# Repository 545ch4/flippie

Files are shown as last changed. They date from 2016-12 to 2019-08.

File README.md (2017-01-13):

# flippie

first flippie test

## Basic idea and some background

Usual story: no money, lots of deadlines, unsustainable promises, social responsibility, no time at all, but the unique opportunity to get an additional time-sink. Yeah. Seconds later, I got two huge flip-dot displays I couldn't even carry myself and a lot of single modules. Soon (measured in seasons) it became obvious, that reverse engineering the RS485 based IBIS bus would not make me very happy in the long run. So I decided to throw away the original controller board and drive the flip-dot modules myself. **The goal would be a non intrusive board to directly connect any BROSE display (or array of the same) through the proprietary 60-pin connector...**  So, this is the story of that effort...

### Flip-dot display in general

A flip-dot display consists of a grid of small magnet embedded discs that are black on one side and a bright color on the other (typically white or yellow). The discs are attached to an axle with separate solenoids arranged at the ends or side. By pulsing the solenoid coil with the appropriate electrical polarity, the permanent magnet on the discs align itself with the magnetic field and thus turning (flipping) the disc.

The matrix schematic arranged on a two-dimensional area is shown below.

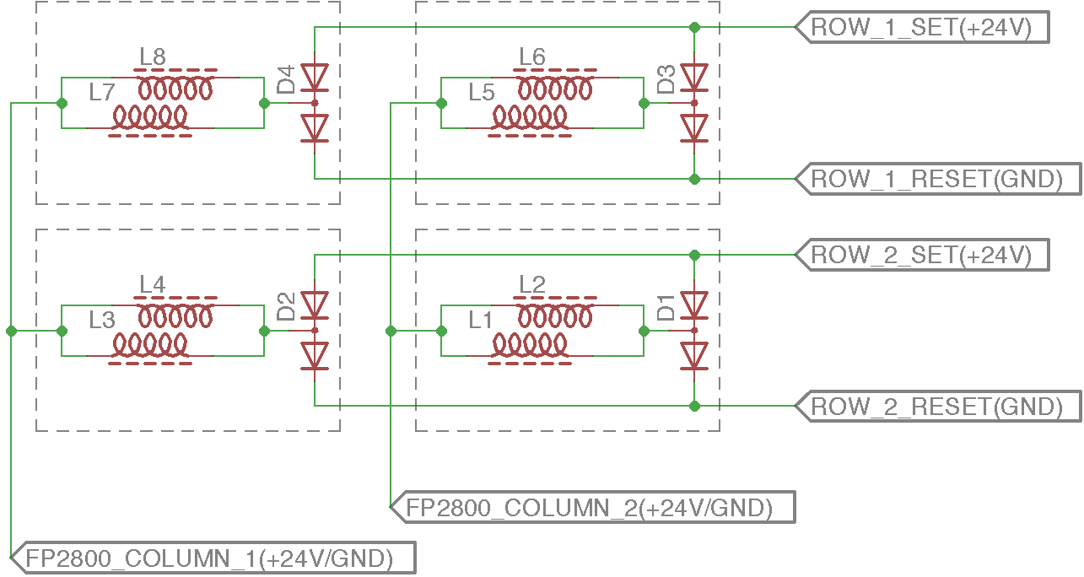
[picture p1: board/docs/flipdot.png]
flip-dot solenoid schematic


### BROSE flip-dot

Most BROSE flip-dots are equipped with an [origial FP2800A (or clone)](https://reaktor23.org/_media/projects/flipdot/fp2800-datasheet.pdf) decoder driver as column-selector. It drives one line addressed by 5-bits (A0, A1, A2, B1 and B2) in the direction of D (GND or +VS).  Based on the truth-table, 28 independent column-lines can be driven.

The address lines (ADDR1..ADDR8) are compared to an DIP-switch on each module using a 74HCT688. The output of that comparison drives the ENABLE pin of the FP2800A (through a discrete inverter).

All data and address lines are at 24V logic level. The VS line should be current limited to 350-400 mA, because the coils and/or the FP2800A may blow at higher current.

I did a reverse engineering of the 24V logic at the BROSE display just for illustration. Download as [PDF](https://github.com/545ch4/flippie/raw/master/board/docs/brose_24v_logic.pdf) or [Eagle SCH](https://github.com/545ch4/flippie/raw/master/board/docs/brose_24v_logic.sch).

### BROSE 60-pin connector

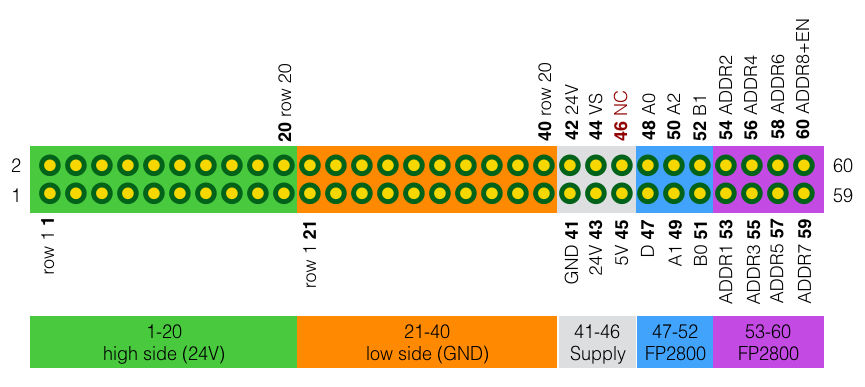
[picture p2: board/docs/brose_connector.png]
Specification of the common 60-pin BROSE connector


## flippie board

The board was designed to drive every serial assembly of modules or single ones non-intrusively - without soldering or modifying the module(s) - simply by connection the proprietary 60-pin BROSE connector. The main MCU [ESP8266](https://espressif.com/en/products/hardware/esp8266ex/overview) is mounted on a USB-interfaced USB-to-Serial converter for convenient programming and WiFi on board. Please see [wemos D1 mini](https://www.wemos.cc/product/d1-mini.html) documentation. Usually you need some driver for the converter to be detected as serial port depending on your OS. The wemos D1 mini comes with a Jiangsu Qinheng CH340/CH341/CH34X or Silicon Labs CP210x chip.

### Block diagram

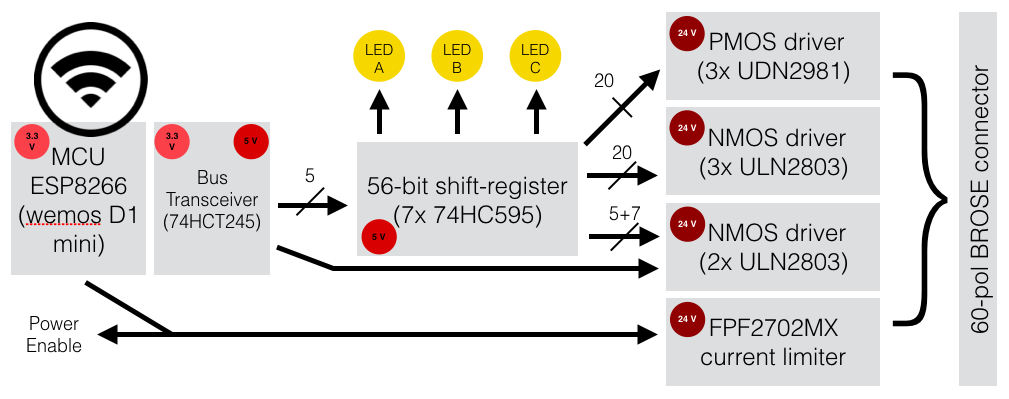
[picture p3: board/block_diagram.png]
flippie block diagram


### Schematics

Since this is my first PCB, the schematic may be slightly unusual. But it works... Suggestions are very welcome. Get the [Eagle SCH file](https://github.com/545ch4/flippie/raw/master/board/flippie.sch) or see the [PDF file](https://github.com/545ch4/flippie/raw/master/board/flippie_schematics.pdf).

### Layout

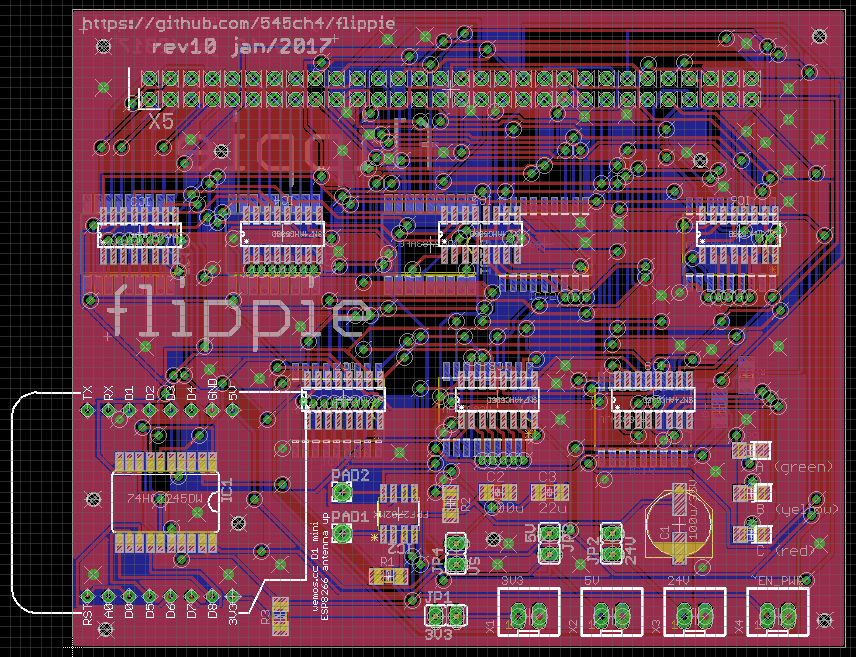
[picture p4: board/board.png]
flippie board


Download the [Eagle BRD](https://github.com/545ch4/flippie/board/flippie.brd) file and/or the generated [GERBER files as ZIP archive](https://github.com/545ch4/flippie/raw/master/board/gerber.zip). All design rules are taken from [SparkFuns Extended Gerber Format](https://github.com/sparkfun/SparkFun_Eagle_Settings/blob/master/cam/sfe-gerb274x-withGBP.cam).

### BOM

| Part | Value | Device | Package | Description |
|---|---|---|---|---|
| Part Value | Device | Package | Description |
| C1 | 100uF/50V | CPOL-EU_E | PANASONIC_E | Polarized capacitor, 50V |
| C2 | 10uF/50V | C-EU_C1206 | C1206 | X7R Ceramic Capacitor, 50V |
| C3 | 1uF/50V | C-EU_C1206 | C1206 | X7R Ceramic Capacitor, 50V |
| IC1 | 74HCT245DW | 74HCT245DW | SO20W | Octal BUS TRANSCEIVER, 3-state, TTL/CMOS |
| IC2 | FPF2702MX | FPF2700 | SO8N | AccuPower 0.4~2 A Adjustable Over-Current Protection Load Switch |
| IC3 | SN74AHC595D | SN74AHC595D | SO16N | 8 bit Shift registers |
| ... | ... | ... | ... | ... |
| IC9 | SN74AHC595D | SN74AHC595D | SO16N | 8 bit Shift registers |
| IC10 | TD62783AFG | UDN2981LW | SO18W | PMOS Darlington transistor array |
| IC11 | TD62783AFG | UDN2981LW | SO18W | PMOS Darlington transistor array |
| IC12 | TD62783AFG | UDN2981LW | SO18W | PMOS Darlington transistor array |
| IC13 | ULN2803A | ULN2803ADW | SO18W | NMOS Darlington transistor array |
| ... | ... | ... | ... | ... |
| IC17 | ULN2803A | ULN2803ADW | SO18W | NMOS Darlington transistor array |
| JP1 | 3V3 | JP1E | JP1 | 3.3V Rail Jumper |
| JP2 | 24V | JP1E | JP1 | 24V Rail Jumper |
| JP3 | 5V | JP1E | JP1 | 5V(VCC) Rail Jumper |
| JP4 | VS | JP1E | JP1 | 24V(VS) Jumper |
| LED1 C (red) | LED_SMT1206 | 1206 | LED |
| LED2 B (yellow) | LED_SMT1206 | 1206 | LED |
| LED3 A (green) | LED_SMT1206 | 1206 | LED |
| MCU1 | WEMOS D1 mini | WEMOS D1 mini | WEMOS D1 mini MCU |
| PAD1 (24V) | 2,15/1,0 | 2,15/1,0 | THROUGH-HOLE PAD |
| PAD2 (VS) | 2,15/1,0 | 2,15/1,0 | THROUGH-HOLE PAD |
| R1 | 680K | R-EU_R1206 | R1206 | Current limiter Resistor R_set |
| R2 | 100K | R-EU_R1206 | R1206 | Resistor |
| R3 | 10K | R-EU_R1206 | R1206 | Resistor |
| R4 | 10K | R-EU_R1206 | R1206 | Resistor |
| R5 | 10K | R-EU_R1206 | R1206 | Resistor |
| R6 | 220 | R-EU_R1206 | R1206 | Resistor |
| R7 | 220 | R-EU_R1206 | R1206 | Resistor |
| R8 | 220 | R-EU_R1206 | R1206 | Resistor |
| X1 | 3V3 | JST-XH-02 | JST-XH-02-PACKAGE-LONG-PAD | JST XH Connector 2 Pin |
| X2 | 5V | JST-XH-02 | JST-XH-02-PACKAGE-LONG-PAD | JST XH Connector 2 Pin |
| X3 | 24V | JST-XH-02 | JST-XH-02-PACKAGE-LONG-PAD | JST XH Connector 2 Pin |
| X4 | ~EN_PWR | JST-XH-02 | JST-XH-02-PACKAGE-LONG-PAD | JST XH Connector 2 Pin |
| X5 | BROSE-60-POL | 057-060-1 | 057-060-1 | 60-pol. BROSE CONNECTOR |

### Soldering notes

You can override the whole current limit circuit by shorting/bridging PAD1 (24V) and PAD2 (VS). If you decided to do so, you don't need to populate C1, C2, C3, R1, R2 and IC2.

> **Close JP1 (3V3) and JP2 (24V) but not JP4 (VS) yet.**

## Code

### Prerequisites

Since building and maintaining an ESP8266 toolchain using the [Arduino ESP8266 Framework](https://github.com/ESP8266/Arduino) can be rather frustrating, I decided to use [PlatformIO](http://platformio.org/platformio-ide) with this project.

1. [Download PlatformIO](http://platformio.org/platformio-ide) and install
2. Launch and follow on-screen instructions (install Python-2.7 if necessary)
3. [Install Clang/LLVM](http://docs.platformio.org/en/stable/ide/atom.html#ide-atom-installation-clang)
4. Ensure `platformio-ide` and `platformio-ide-terminal` are enabled (*"Settings > Packages"*)

### Open the project

Download or clone this repository. Open the directory `./code/server` using *"Open project"* at PlatformIO IDE.

### Necessary adoptions

Review you flip-dot addresses: **ADDR8 (8 on the DIP-switch) must be in ON state. We are emulating an overall-enable-pin with that one. Further, the addresses are inverted. So, address 0x01 matches the DIP-switch configuration 1-OFF, 2-ON, ..., 7-ON an 8-ON.**

Before you compile and upload your custom firmware to the ESP8266, there are some values specific to your setup/environment to be defined.
**Flip-dot configuration at `code/server/flippie_device.cpp`:**
```c++
// TODO: How many modules does your display consists of?
const unsigned int num_modules = 4;
config.num_modules = num_modules;
// TODO: What are the addresses (as decimal) of the modules? (see DIP-switches at each module)
config.addresses = new unsigned int[num_modules]{1, 2, 4, 8};
// TODO: How many rows does your display have? (equal over all modules)
config.num_rows = 18;
// TODO: How many columns does each module of your display have? (same order as the addresses)
config.num_columns = new unsigned int[num_modules]{28, 28, 28, 21};
// TODO: Should LED C toggle on each shift-register firing?
config.led_mode = LED_MODE_FLASHING;
```

**WiFi configuration at `code/server/main.cpp`:**
```c++
// TODO: What's the SSID of your WiFi?
const char* ssid = "SSID";
// TODO: What's the PASSWORD of your WiFi?
const char* password = "PASSWORD";
// TODO: If you don't want to use DHCP, provide a static IP (uncomment the following lines). Otherwise leave this commented.
// IPAddress ip(192, 168, 1, 23);
// IPAddress gateway(192, 168, 1, 1);
// IPAddress subnet(255, 255, 255, 0);
// WiFi.config(ip, gateway, subnet);
```

### Compile and upload firmware

> **Please disconnect the power supply of your flippie board or remove the jumper JP1 und JP3 before connecting your computer to the USB port of the ESP8266 (if mounted at the flippie board already).**

Navigate to *"PlatformIO > Build"* to compile this project and create the firmware for uploading to the ESP8266. Use *"PlatformIO > Upload"* to upload your firmware using the USB connection.

### Test

Disconnect flippie from USB or press the reset button of the wemos D1 mini board. Plug the wemos D1 mini to flippie, ensure to close JP1 (3V3), JP2 (24V) and JP3 (5V) **but not JP4 (VS) yet**. All three LEDs should flash three times. If not, the shift-register(s) doesn't seems to work properly... [So, check your soldering.](http://www.infidigm.net/articles/solder/)

If the LEDs were flashing during boot-up, don't yet connect the display itself. Point your browser to `http://<flippie IP>/`. That's the web-interface of flippie. You've done well so far.

Since you don't want to damage your display, we will try to set and reset some dots in a dry run first (**AKA: don't connect your flipdot display yet**):

0. Make sure your display is **not** connected (X5), jumper JP4 (VS) is **closed/shorted** and all three power rails (3V3, 5V and 24V) are enabled through JP1, JP2, JP3.
1. Head to "Low Level" in at flippies web-interface.
2. Fill the form for
   1. Select the address of one of your panels (e.g. 1)
   2. Select a column we are going to use (Column, e.g. 10)
   3. Set "Row SET" to '0' (first row)
   4. Leave "Row RST" undefined
   5. Set the direction D to "1" (D=1 when setting (ROW_SET) and D=0 when reseting (ROW_RST) a pixel)
4. Press "Fire shift-register (PERSISTENT)"
   1. IC12 pin 11 should drive +24V (first row rail, same as pin 1 at X5)
   2. IC16 pin 18 should go to GND (our simulated ENABLE signal, same as pin 60 at X5)
5. Press "Fire shift-register (ENABLE)" to quit "PERSISTENT" mode.

Repeat the test with flipdot display connected (X5):

0. Make sure your display **is** connected (X5), jumper JP4 (VS) is **open** and all three power rails (3V3, 5V and 24V) are enabled through JP1, JP2, JP3.
1. Head to "Low Level" in at flippies web-interface.
2. Fill the form for
   1. Select the address of one of your panels (e.g. 1)
   2. Select a column we are going to use (Column, e.g. 10)
   3. Set "Row SET" to '0' (first row)
   4. Leave "Row RST" undefined
   5. Set the direction D to "1" (D=1 when setting (ROW_SET) and D=0 when reseting (ROW_RST) a pixel)
4. Press "Fire shift-register (PERSISTENT)"
5. Now take a jumper and use it to **shortly bypass** (close shortly and then open again) JP4 (VS): **The dot should flip!**
6. Repeat the procedure with "Row SET" undefined, "Row RST" set to '0' and D set to '0'. **The dot should flip back!**
5. Press "Fire shift-register (ENABLE)" to quit "PERSISTENT" mode.

**Well done!** You're ready to use your flippie! [Simply head over to "Paint" and draw something.](#paint)

### Firmware API documentation

Flippie is basically a simple web server at port 80 serving the following access points:

**`/ui` – UI pages**  
A simple index page with browser UI controlling the flip-dot. All javascript and stylesheets are loaded from an external CDN, not from the ESP8266 itself. So, you need to be connected to the internet... (Yes, it's an TODO.)

The UI does have a nice drawing pane, where every pixel can be set/reset like painting using a HTML5 canvas.

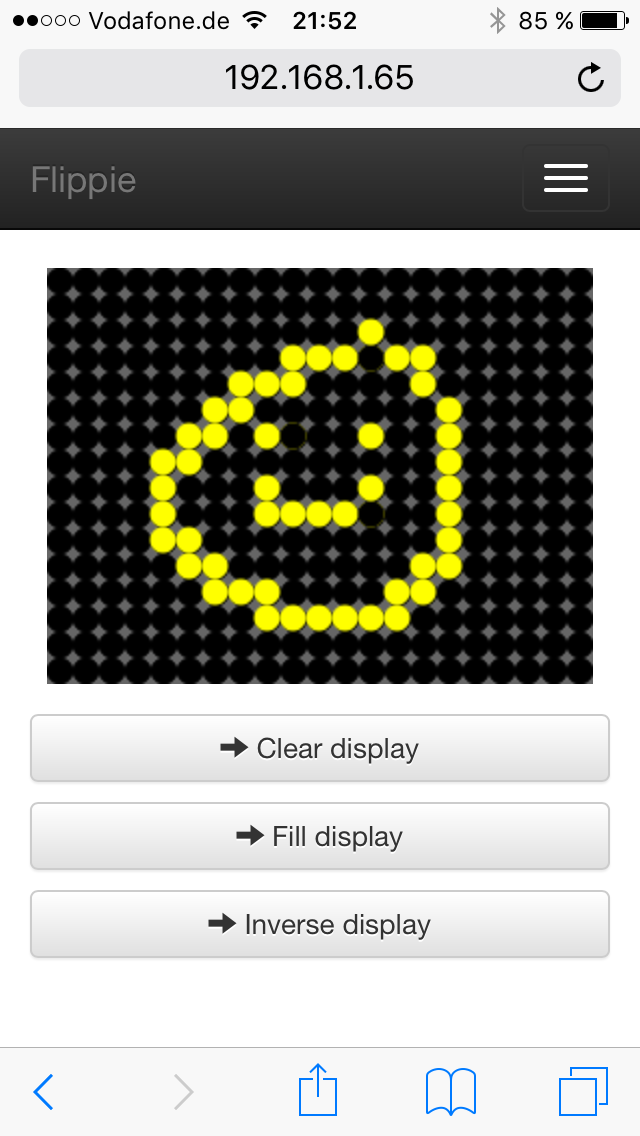
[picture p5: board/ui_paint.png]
flippie ui paint pane


**`/dots` – A receiver of base64 encoded dots vector**  
This method reads the content of HTTP (POST/GET) variable `dots` which is a base64 encoded string. This string is build of 32-bit wide integers (four bytes) where each bit (0-31) represents the state of one column. Those integers are ordered by rows and then modules:
```
[row 1 column 1-32* module 1], [row 1 column 1-32* module 2], ..., [row 1 column 1-32* module M], [row 2 column 1-32* module 1], [row 2 column 1-32* module 2], ..., ..., [row R column 1-32* module M]
```
\* max, could be less, ignoring unnecessary bits. Each integer is packed as four 8-bit characters in LSB order.

**`/flippie` – Directly alter the shift register at flippie (possibly dangerous)**

Low level access to flippie. Set using HTTP variables (POST) and retrieve values as JSON using GET. POST request will return JSON `true`.

| HTTP verb | Variable | Value | Description |
|---|---|--- |---|
| GET/POST  | led_X | 0, 1 | Get/Set the state of LED X (A, B, C) |
| GET/POST  | address | 0 - 127 | Get/Set the module address |
| GET/POST  | column | 0 - 27 | Get/Set the active column |
| GET/POST  | d | 0, 1 | Set FP2800A D pin (1 = selected column set to GND, 0 = selected column set to +VS) |
| GET/POST  | row_set | 0 - 19 | Set the selected row to +VS |
| GET/POST  | row_rst | 0 - 19 | Set the selected row to GND |
| GET/POST  | enable | 0, 1 | Set enable if 1 (dangerous) |
| POST | clear | 0, 1 | Clear shift-register if 1 |
| GET | shiftregister  | String | Get contents of the shift-register as sequence of zeros and ones. |
| POST | task | clear | Clear the whole display |
| POST | task | fill | Fill the whole display (set all dots) |
| POST | task | inverse | Inverse the whole display |
| POST | task | magnetize | Magnetize the whole display |

Basic mechanism to set a dot (column 2, row 3) at module 0 with address 0x01 (DIP switch 0-1-1-1-1-1-1-0) using raw HTTP:
```shell
$ telnet <flippie IP> 80
> POST /flippie HTTP/1.0
> Content-Length: 41
>
> address=1&column=1&row_set=2&d=1&enable=1
```

**`/pixel` – Set individual pixels**

| HTTP Variable | Description |
|---|---|
| r(0-31) | Row |
| m(0-128) | Module |
| c(0-31) | Column |
| state(0/1) | Set of reset the pixel |

A GET request will reveal the state of an pixel and a POST will set the state.

## Demo ruby client

There's a simple demo-like ruby implementation to write text at a given display. To use it, please head yourself to the directory `./client/` and initialize the ruby environment with:
```shell
gem install bundler
bundle install
```

Adjust flippies credentials in `cli.rb`:
```ruby
# initialize new flippie client
fc = FlippieClient.new(
   '192.168.1.23',     # IP address of your flippie board
   18,                  # number of rows of your flip-dot display
   [21],                # number of columns per module (usually some 28ers an one 21er)
   false                # debug => true
)
```

You are now ready to send messages/text to your flippie board using the ruby tool. Example:
```shell
./cli.rb YES
```
You should see an visual response of "YES" on your command line as well as the same text on your flip-dot display, obviously. See the source for further options.

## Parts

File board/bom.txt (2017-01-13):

| Part Value | Device | Package | Description |
| C1 | 100uF/50V | CPOL-EU_E | PANASONIC_E | Polarized capacitor, 50V |
| C2 | 10uF/50V | C-EU_C1206 | C1206 | X7R Ceramic Capacitor, 50V |
| C3 | 1uF/50V | C-EU_C1206 | C1206 | X7R Ceramic Capacitor, 50V |
| IC1 | 74HCT245DW | 74HCT245DW | SO20W | Octal BUS TRANSCEIVER, 3-state, TTL/CMOS |
| IC2 | FPF2702MX | FPF2700 | SO8N | AccuPower 0.4~2 A Adjustable Over-Current Protection Load Switch |
| IC3 | SN74AHC595D | SN74AHC595D | SO16N | 8 bit Shift registers |
| IC4 | SN74AHC595D | SN74AHC595D | SO16N | 8 bit Shift registers |
| IC5 | SN74AHC595D | SN74AHC595D | SO16N | 8 bit Shift registers |
| IC6 | SN74AHC595D | SN74AHC595D | SO16N | 8 bit Shift registers |
| IC7 | SN74AHC595D | SN74AHC595D | SO16N | 8 bit Shift registers |
| IC8 | SN74AHC595D | SN74AHC595D | SO16N | 8 bit Shift registers |
| IC9 | SN74AHC595D | SN74AHC595D | SO16N | 8 bit Shift registers |
| IC10 | TD62783AFG | UDN2981LW | SO18W | PMOS Darlington transistor array |
| IC11 | TD62783AFG | UDN2981LW | SO18W | PMOS Darlington transistor array |
| IC12 | TD62783AFG | UDN2981LW | SO18W | PMOS Darlington transistor array |
| IC13 | ULN2803A | ULN2803ADW | SO18W | NMOS Darlington transistor array |
| IC14 | ULN2803A | ULN2803ADW | SO18W | NMOS Darlington transistor array |
| IC15 | ULN2803A | ULN2803ADW | SO18W | NMOS Darlington transistor array |
| IC16 | ULN2803A | ULN2803ADW | SO18W | NMOS Darlington transistor array |
| IC17 | ULN2803A | ULN2803ADW | SO18W | NMOS Darlington transistor array |
| JP1 | 3V3 | JP1E | JP1 | 3.3V Rail Jumper |
| JP2 | 24V | JP1E | JP1 | 24V Rail Jumper |
| JP3 | 5V | JP1E | JP1 | 5V(VCC) Rail Jumper |
| JP4 | VS | JP1E | JP1 | 24V(VS) Jumper |
| LED1 C (red) | LED_SMT1206 | 1206 | LED |
| LED2 B (yellow) | LED_SMT1206 | 1206 | LED |
| LED3 A (green) | LED_SMT1206 | 1206 | LED |
| MCU1 | WEMOS D1 mini | WEMOS D1 mini | WEMOS D1 mini MCU |
| PAD1 (24V) | 2,15/1,0 | 2,15/1,0 | THROUGH-HOLE PAD |
| PAD2 (VS) | 2,15/1,0 | 2,15/1,0 | THROUGH-HOLE PAD |
| R1 | 680K | R-EU_R1206 | R1206 | Current limiter Resistor R_set |
| R2 | 100K | R-EU_R1206 | R1206 | Resistor |
| R3 | 10K | R-EU_R1206 | R1206 | Resistor |
| R4 | 10K | R-EU_R1206 | R1206 | Resistor |
| R5 | 10K | R-EU_R1206 | R1206 | Resistor |
| R6 | 220 | R-EU_R1206 | R1206 | Resistor |
| R7 | 220 | R-EU_R1206 | R1206 | Resistor |
| R8 | 220 | R-EU_R1206 | R1206 | Resistor |
| X1 | 3V3 | JST-XH-02 | JST-XH-02-PACKAGE-LONG-PAD | JST XH Connector 2 Pin |
| X2 | 5V | JST-XH-02 | JST-XH-02-PACKAGE-LONG-PAD | JST XH Connector 2 Pin |
| X3 | 24V | JST-XH-02 | JST-XH-02-PACKAGE-LONG-PAD | JST XH Connector 2 Pin |
| X4 | ~EN_PWR | JST-XH-02 | JST-XH-02-PACKAGE-LONG-PAD | JST XH Connector 2 Pin |
| X5 | BROSE-60-POL | 057-060-1 | 057-060-1 | 60-pol. BROSE CONNECTOR |

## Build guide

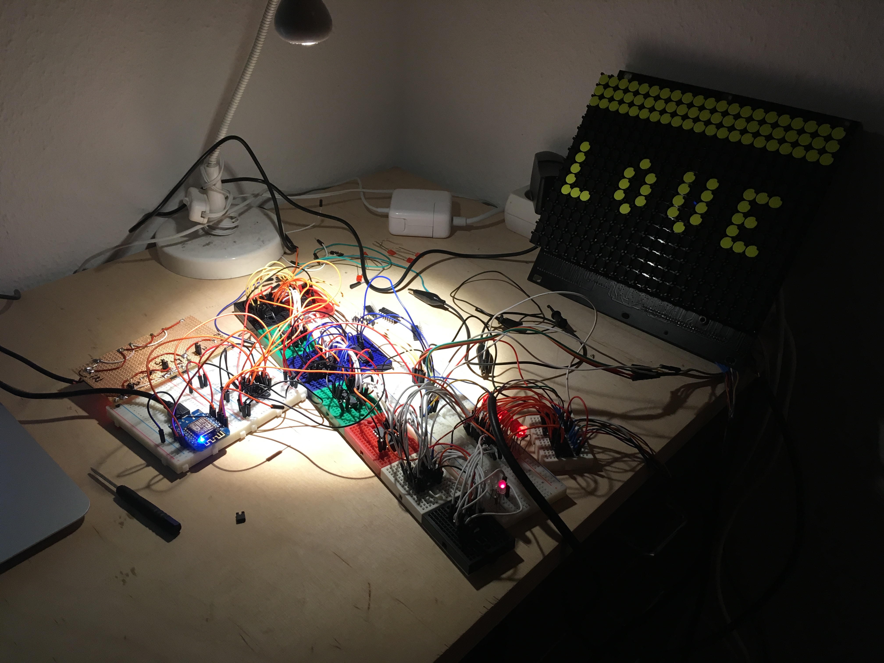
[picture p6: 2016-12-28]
board/docs/flippie_first_setup_1.jpg

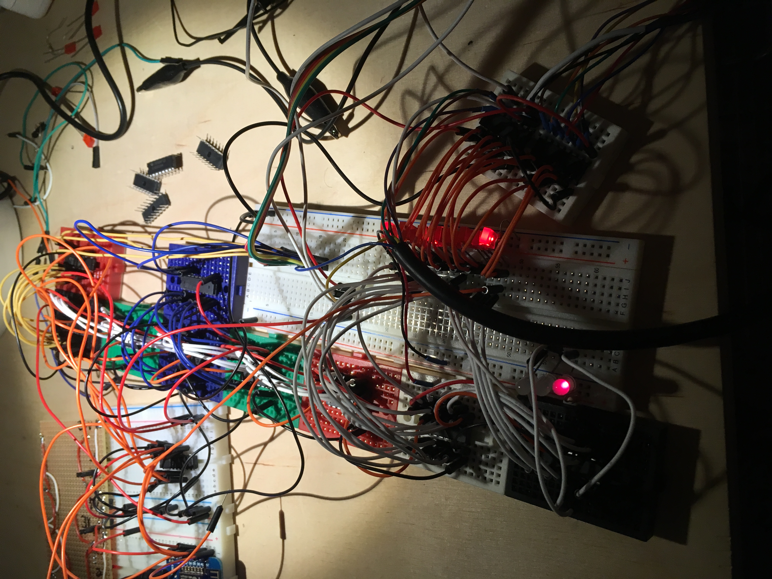
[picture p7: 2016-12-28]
board/docs/flippie_first_setup_2.jpg

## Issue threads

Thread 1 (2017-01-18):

Addresses fixed by board

soundstorm, 2017-01-18:
The addresses are fixed by the ADDR8/EN pin on PCB, if daisy chaining them, ADDR1-ADDR8 must correspond the panels DIP switch position (which should be different than always 00000001). So the addr shift register needs to be filled and toggled once.
[I already built a shift-register only pcb](https://github.com/ArduinoHannover/FlipperCTRL), but missed the current limit on VS and got the address problem too, as my last register is synced with the others. Will fix that in next revision.

545ch4, 2017-02-06:
I don't quite understand your issue here. Let's just explain my thoughts on this "address-problem" at flippie:

The address lines (as well as the FP2800A inputs) are 24V pulled-up logic lines. So to drive them in a very simple way would need just as NMOS to short the line to GND. By doing so, you have an inverting driver. That's why the modules connected via flippie, must have their address DIP-switches on the module inverted.

I've designed the ADDR8/EN line directly as an discrete output of the MCU to emulate a real kill-switch-like EN line. All other lines ADDR1-ADDR7 are driven by the shift-register.

So, there's no "address-problem" at flippie. It is working with multiple modules (tested).

soundstorm, 2017-02-21:
Nah, missed that in the Readme... Nevermind. 128 Displays should be enough...

Closed 2017-02-21.

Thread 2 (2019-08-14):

LEDs not flashing / Wemos D1 Mini restarts when /ui/ is started in the browser

transbend, 2019-08-14:
_Disclaimer: I'm relatively new to electronics, so I guess it could also be a very easy mistake I made. But I would really appreciate some help :(_

When booting the Wemos D1 Mini the three LEDs are not flashing, but only turning off, and after they should have been flashing three times, they are turning on again.

Also when I try to go to flippie-IP in the browser, the Wemos restarts and I get this Error in the serial monitor:

```
Exception (3):
epc1=0x4020ce0c epc2=0x00000000 epc3=0x00000000 excvaddr=0x4024acbf depc=0x00000000

>>>stack>>>

ctx: cont

sp: 3ffffd00 end: 3fffffc0 offset: 01a0
3ffffea0:  4024acbf 3fff019c 3fffff10 00000001
3ffffeb0:  3fff0574 3fff019c 3fffff10 402034c7
3ffffec0:  00000000 00000000 ffffff10 4020752e
3ffffed0:  00000000 3fffdad0 3fffff10 4020758e
3ffffee0:  3ffe879b 3fff01e0 3fffff10 40207734
3ffffef0:  ffffffff 3fff01e0 3fff019c 402033a0
3fffff00:  3fff0574 3fff01e0 3fff019c 40205479
3fffff10:  2f69752f 00000000 00000000 00000000
3fffff20:  ff544820 4bc6a7f0 00006175 3ffeebec
3fffff30:  3fff01c4 3fff0250 00000001 3fff01c4
3fffff40:  00000001 3ffeebec 00000000 0000000f
3fffff50:  00000000 3fff063c 3fff019c 3ffeebec
3fffff60:  00000001 3fff01c4 3fff019c 4020567c
3fffff70:  4020a858 00000000 00001388 4020a918
3fffff80:  00000000 3fff063c feefeffe feefeffe
3fffff90:  3fffdad0 00000000 3ffeebbc 40203759
3fffffa0:  3fffdad0 00000000 3ffeebbc 402084b8
3fffffb0:  feefeffe feefeffe 3ffe850c 401004d9
<<<stack<<<

�L␀A␋␁␁��       �␌%��u�␁�␌)Q
␑Z-�Xʋ'��E␋␒��␑\��Q�    )l�5␑␁�␏␑␅␂�NRP␋JJk�A␌X-C�
Booting...
```

Following your instructions it must be something wrong with my shift registers, I guess, but I can't figure out what is wrong.. I triple checked my soldering, also under the microscope, but it seems all fine.

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

545ch4, 2019-08-14:
Sorry to hear that things didn't work as supposed :(

Have you tried to enable debugging via set ```#define DEBUG 1``` in ```src/debug.h```?

Are you attending the [CCCamp2019](https://www.ccc.de/de/updates/2019/camp-zelte)? Then we could meet in person and fix this issue.

transbend, 2019-08-16:
Dear 545ch4, thanks so much for your fast reply! I will try enabling debugging today.

I'm not going to CCCamp (because I'm doing my bachelor thesis atm), but I really appreciate that you would take some time for me :)

transbend, 2019-08-16:
Hi :)

When enabling the debug mode, in the serial monitor I get this:

`load 0x4010f000, len 1384, room 16
tail 8
chksum 0x2d
csum 0x2d
v8b899c12
~ld

Booting...
.
Connected to 'wifi'
IP address: '192.168.123.134'
Finished configure flippie.
Finished defining and setting all output pins.
Fireing shift-register (enable=false, persistant=false)... xDONE.
Fireing shift-register (enable=false, persistant=false)... xDONE.
Fireing shift-register (enable=false, persistant=false)... xDONE.
Fireing shift-register (enable=false, persistant=false)... xDONE.
Fireing shift-register (enable=false, persistant=false)... xDONE.
Fireing shift-register (enable=false, persistant=false)... xDONE.

Finished first test of shift-register.
Finished initilizing flippie.
Added UIHandler
Added DotsHandler
Added PixelHandler
Added FlippieHandler
Added NotFoundHandler
Ready! Open http://192.168.123.134 in your browser`

Are the lines `Fireing shift-register (enable=false, persistant=false)... xDONE.` supposed to say something else, when it is working?

545ch4, 2019-08-24:
Figured out why you got the exception: In the current version of the ESP SDK the PROGMEM string foo has changed rendering the ´.send()´ method to exit with exception. Please see my latest commit.

transbend, 2019-08-25:
How cool! Thanks a lot! :) I just updated your firmware for the MCU and I now it forwards to /ui/ without restarting.

But still the LEDs are not flashing when resetting the D1 mini.. Though in the serial monitor it says `Fireing shift-register (enable=false, persistant=false)... xDONE.` a few times. On reset the LEDs turn off and as the first "Fireing shift-register" comes in the serial monitor, alls LEDs stay turned on again without flashing..

Can it be that they don't flash, when you bridge the current limiter with the Pads 1 and 2? Or do I have to close the ~EN_PWR connection? Also I just replaced all shift registers from the board to check if one doesn't work, but still the LEDs don't flash.

545ch4, 2019-09-02:
The LEDS are on the very end of the sift register. Thus, if the LED flashing is not working, it is very likely that some of the shift register is not connected properly to the next one. Check if pin 9 is connected to the following 595 pin 14.

Closed 2019-08-24.

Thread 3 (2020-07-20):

Question about dip-switch

javl, 2020-07-20:
Thanks for your detailed explanation and schematics. I finally got my hands on 4 16x28 flip-dot units and your project looks like a great starting point to get them to work.

There is just one part I'm unclear of. In the setup you write:

```
ADDR8 (8 on the DIP-switch) must be in ON state. We are emulating an overall-enable-pin with that one.
```

Which sounds like all modules will be enabled at the same time, but in the config file you write:

```
// TODO: What are the addresses (as decimal) of the modules? (see DIP-switches at each module)
config.addresses = new unsigned int[num_modules]{1, 2, 4, 8};

```

Would you mind explaining what you mean exactly?

javl, 2020-07-20:
OK, just realized there was a closes issue where this is explained, sorry.

Closed 2020-07-20.

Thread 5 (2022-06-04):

Boards for sale?

PeterEhses, 2022-06-04:
Hi,
I have a flipdot matrix in need of controlling but want to get around assembling a board myself since some components are on backorder until next year. Is this board, assembled or as parts, for sale anywhere, or is anyone willing and able to sell me a spare one / spare components?
If this is the wrong place to ask, please close / remove.
Thanks in advance!

RobsyRocket, 2022-06-04:
Hey, you are locate in Germany if I got it right from your profile. Have a look at the following links and you will find used boards from different manufactures.

* Brose https://www.homburg-sohn-et.de/340735220/category/1333400
* Lawo https://www.homburg-sohn-et.de/340735220/category/1549838
* AEG https://www.homburg-sohn-et.de/340735220/category/1571336
* Mixed parts with some displays in between https://www.homburg-sohn-et.de/340735220/category/191632

They sell parts from old buses and are really nice and helpful. I picked up my first modules locally but they ship them as well. Over the years I got from them 15-20 boards of different shapes and brands.

If you need more pictures or other quantities, then call or mail them. Usually there is more available than shown online.

Good luck and report here or as DM what you bought. 😀

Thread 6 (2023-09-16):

Power draw

yoxcu, 2023-09-16:
First of all, nice project!

Is there any information on power draw from the 24V, 5V, and 3.3V supplies?

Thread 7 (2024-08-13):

Kombilierung bricht mit Fehler ab.

MG020162, 2024-08-13:
Wenn ich den code mit Platformio kombiliere erhalte ich folgende Fehler:

 *  Executing task: C:\Users\m-gri\.platformio\penv\Scripts\platformio.exe run

Processing esp12e (platform: espressif8266; framework: arduino; board: esp12e)
-----------------------------------------------------------------------------Verbose mode can be enabled via `-v, --verbose` option
CONFIGURATION: https://docs.platformio.org/page/boards/espressif8266/esp12e.html
PLATFORM: Espressif 8266 (4.2.1) > Espressif ESP8266 ESP-12E
HARDWARE: ESP8266 80MHz, 80KB RAM, 4MB Flash
PACKAGES:
 - framework-arduinoespressif8266 @ 3.30102.0 (3.1.2)
 - tool-esptool @ 1.413.0 (4.13)
 - tool-esptoolpy @ 1.30000.201119 (3.0.0)
 - toolchain-xtensa @ 2.100300.220621 (10.3.0)
Converting flippie.ino
LDF: Library Dependency Finder -> https://bit.ly/configure-pio-ldf
LDF Modes: Finder ~ chain, Compatibility ~ soft
Found 38 compatible libraries
Scanning dependencies...
Dependency Graph
|-- NTPClient @ 3.2.1+sha.0d7162f
|-- ESP8266WebServer @ 1.0
|-- ESP8266WiFi @ 1.0
Building in release mode
Compiling .pio\build\esp12e\src\flippie.ino.cpp.o
Compiling .pio\build\esp12e\src\handler\abstract_handler.cpp.o
Compiling .pio\build\esp12e\src\handler\dots_handler.cpp.o
Compiling .pio\build\esp12e\src\handler\flippie_handler.cpp.o
Compiling .pio\build\esp12e\src\handler\not_found_handler.cpp.o
Compiling .pio\build\esp12e\src\handler\pixel_handler.cpp.o
Compiling .pio\build\esp12e\src\handler\ui_handler.cpp.o
Compiling .pio\build\esp12e\src\main.cpp.o
D:/flippie-master/code/server/src/flippie.ino: In member function 'void Flippie::inverse()':
D:/flippie-master/code/server/src/flippie.ino:257:17: warning: unused variable 'x' [-Wunused-variable]
  257 |   unsigned char x = 0;
      |                 ^
D:/flippie-master/code/server/src/flippie.ino: In member function 'void Flippie::fill()':
D:/flippie-master/code/server/src/flippie.ino:280:17: warning: unused variable 'x' [-Wunused-variable]
  280 |   unsigned char x = 0;
      |                 ^
D:/flippie-master/code/server/src/flippie.ino: In member function 'String Flippie::dots_as_string(unsigned int**)':
D:/flippie-master/code/server/src/flippie.ino:723:45: warning: comparison of
integer expressions of different signedness: 'unsigned int' and 'int' [-Wsign-compare]
  723 |         c[c_len++] = ((dots[i][j] & 1 << k) == 1 << k) ? '@' : '.';
      |                       ~~~~~~~~~~~~~~~~~~~~~~^~~~~~~~~
D:/flippie-master/code/server/src/flippie.ino: In member function 'String Flippie::shift_register_as_json()':
D:/flippie-master/code/server/src/flippie.ino:737:17: warning: unused variable 'r_len' [-Wunused-variable]
  737 |   unsigned char r_len =
      |                 ^~~~~
In file included from C:\Users\m-gri\.platformio\packages\framework-arduinoespressif8266\libraries\ESP8266WebServer\src/ESP8266WebServer-impl.h:30,
                 from C:\Users\m-gri\.platformio\packages\framework-arduinoespressif8266\libraries\ESP8266WebServer\src/ESP8266WebServer.h:349,
                 from src\handler\abstract_handler.h:4,
                 from src\handler\dots_handler.h:5,
                 from src\handler\dots_handler.cpp:1:
C:\Users\m-gri\.platformio\packages\framework-arduinoespressif8266\libraries\ESP8266WebServer\src/detail/RequestHandlersImpl.h: In function 'String esp8266webserver::calcETag(fs::FS&, const String&)':
C:\Users\m-gri\.platformio\packages\framework-arduinoespressif8266\libraries\ESP8266WebServer\src/detail/RequestHandlersImpl.h:27:21: error: 'base64' has
not been declared
   27 |     result = "\"" + base64::encode(md5_buf, 16, false) + "\"";
      |                     ^~~~~~
In file included from C:\Users\m-gri\.platformio\packages\framework-arduinoespressif8266\libraries\ESP8266WebServer\src/ESP8266WebServer.h:349,
                 from src\handler\abstract_handler.h:4,
                 from src\handler\dots_handler.h:5,
                 from src\handler\dots_handler.cpp:1:
C:\Users\m-gri\.platformio\packages\framework-arduinoespressif8266\libraries\ESP8266WebServer\src/ESP8266WebServer-impl.h: In member function 'bool esp8266webserver::ESP8266WebServerTemplate<ServerType>::authenticate(const char*, const char*)':
C:\Users\m-gri\.platformio\packages\framework-arduinoespressif8266\libraries\ESP8266WebServer\src/ESP8266WebServer-impl.h:118:24: error: 'base64' has not
been declared
  118 |       String encoded = base64::encode(raw, false);
      |                        ^~~~~~
In file included from C:\Users\m-gri\.platformio\packages\framework-arduinoespressif8266\libraries\ESP8266WebServer\src/ESP8266WebServer-impl.h:30,
                 from C:\Users\m-gri\.platformio\packages\framework-arduinoespressif8266\libraries\ESP8266WebServer\src/ESP8266WebServer.h:349,
                 from src\handler\abstract_handler.h:4,
                 from src\handler\abstract_handler.cpp:1:
C:\Users\m-gri\.platformio\packages\framework-arduinoespressif8266\libraries\ESP8266WebServer\src/detail/RequestHandlersImpl.h: In function 'String esp8266webserver::calcETag(fs::FS&, const String&)':
C:\Users\m-gri\.platformio\packages\framework-arduinoespressif8266\libraries\ESP8266WebServer\src/detail/RequestHandlersImpl.h:27:21: error: 'base64' has
not been declared
   27 |     result = "\"" + base64::encode(md5_buf, 16, false) + "\"";
      |                     ^~~~~~
In file included from src\handler\dots_handler.h:5,
                 from src\handler\dots_handler.cpp:1:
src\handler\abstract_handler.h: At global scope:
src\handler\abstract_handler.h:8:17: error: 'virtual bool AbstractHandler::canHandle(HTTPMethod, String)' marked 'override', but does not override
    8 |    virtual bool canHandle(HTTPMethod method, String uri) override;
      |                 ^~~~~~~~~
src\handler\abstract_handler.h:9:17: error: 'virtual bool AbstractHandler::handle(ESP8266WebServer&, HTTPMethod, String)' marked 'override', but does not
override
    9 |    virtual bool handle(ESP8266WebServer& server, HTTPMethod method, String uri) override;
      |                 ^~~~~~
In file included from C:\Users\m-gri\.platformio\packages\framework-arduinoespressif8266\libraries\ESP8266WebServer\src/ESP8266WebServer.h:349,
                 from src\handler\abstract_handler.h:4,
                 from src\handler\abstract_handler.cpp:1:
C:\Users\m-gri\.platformio\packages\framework-arduinoespressif8266\libraries\ESP8266WebServer\src/ESP8266WebServer-impl.h: In member function 'bool esp8266webserver::ESP8266WebServerTemplate<ServerType>::authenticate(const char*, const char*)':
C:\Users\m-gri\.platformio\packages\framework-arduinoespressif8266\libraries\ESP8266WebServer\src/ESP8266WebServer-impl.h:118:24: error: 'base64' has not
been declared
  118 |       String encoded = base64::encode(raw, false);
      |                        ^~~~~~
src\handler\dots_handler.cpp: In member function 'virtual bool DotsHandler::handle(ESP8266WebServer&, HTTPMethod, String)':
src\handler\dots_handler.cpp:15:69: warning: unused variable 'k' [-Wunused-variable]
   15 |       unsigned int dots_bytes_length = dots.length(), i = 0, j = 0, k = 0;
      |                                                                     ^In file included from src\handler\abstract_handler.cpp:1:
src\handler\abstract_handler.h: At global scope:
src\handler\abstract_handler.h:8:17: error: 'virtual bool AbstractHandler::canHandle(HTTPMethod, String)' marked 'override', but does not override
    8 |    virtual bool canHandle(HTTPMethod method, String uri) override;
      |                 ^~~~~~~~~
src\handler\abstract_handler.h:9:17: error: 'virtual bool AbstractHandler::handle(ESP8266WebServer&, HTTPMethod, String)' marked 'override', but does not
override
    9 |    virtual bool handle(ESP8266WebServer& server, HTTPMethod method, String uri) override;
      |                 ^~~~~~
In file included from C:\Users\m-gri\.platformio\packages\framework-arduinoespressif8266\libraries\ESP8266WebServer\src/ESP8266WebServer-impl.h:30,
                 from C:\Users\m-gri\.platformio\packages\framework-arduinoespressif8266\libraries\ESP8266WebServer\src/ESP8266WebServer.h:349,
                 from src\handler\not_found_handler.h:4,
                 from src\handler\not_found_handler.cpp:1:
C:\Users\m-gri\.platformio\packages\framework-arduinoespressif8266\libraries\ESP8266WebServer\src/detail/RequestHandlersImpl.h: In function 'String esp8266webserver::calcETag(fs::FS&, const String&)':
C:\Users\m-gri\.platformio\packages\framework-arduinoespressif8266\libraries\ESP8266WebServer\src/detail/RequestHandlersImpl.h:27:21: error: 'base64' has
not been declared
   27 |     result = "\"" + base64::encode(md5_buf, 16, false) + "\"";
      |                     ^~~~~~
src\handler\abstract_handler.cpp: In member function 'String AbstractHandler::argsToString(ESP8266WebServer&)':
src\handler\abstract_handler.cpp:6:30: warning: comparison of integer expressions of different signedness: 'unsigned int' and 'int' [-Wsign-compare]
    6 |    for(unsigned int i = 0; i < server.args(); i++) {
      |                            ~~^~~~~~~~~~~~~~~
In file included from C:\Users\m-gri\.platformio\packages\framework-arduinoespressif8266\libraries\ESP8266WebServer\src/ESP8266WebServer.h:349,
                 from src\handler\not_found_handler.h:4,
                 from src\handler\not_found_handler.cpp:1:
C:\Users\m-gri\.platformio\packages\framework-arduinoespressif8266\libraries\ESP8266WebServer\src/ESP8266WebServer-impl.h: In member function 'bool esp8266webserver::ESP8266WebServerTemplate<ServerType>::authenticate(const char*, const char*)':
C:\Users\m-gri\.platformio\packages\framework-arduinoespressif8266\libraries\ESP8266WebServer\src/ESP8266WebServer-impl.h:118:24: error: 'base64' has not
been declared
  118 |       String encoded = base64::encode(raw, false);
      |                        ^~~~~~
In file included from C:\Users\m-gri\.platformio\packages\framework-arduinoespressif8266\libraries\ESP8266WebServer\src/ESP8266WebServer-impl.h:30,
                 from C:\Users\m-gri\.platformio\packages\framework-arduinoespressif8266\libraries\ESP8266WebServer\src/ESP8266WebServer.h:349,
                 from src\handler\abstract_handler.h:4,
                 from src\handler\pixel_handler.h:3,
                 from src\handler\pixel_handler.cpp:1:
C:\Users\m-gri\.platformio\packages\framework-arduinoespressif8266\libraries\ESP8266WebServer\src/detail/RequestHandlersImpl.h: In function 'String esp8266webserver::calcETag(fs::FS&, const String&)':
C:\Users\m-gri\.platformio\packages\framework-arduinoespressif8266\libraries\ESP8266WebServer\src/detail/RequestHandlersImpl.h:27:21: error: 'base64' has
not been declared
   27 |     result = "\"" + base64::encode(md5_buf, 16, false) + "\"";
      |                     ^~~~~~
In file included from C:\Users\m-gri\.platformio\packages\framework-arduinoespressif8266\libraries\ESP8266WebServer\src/ESP8266WebServer-impl.h:30,
                 from C:\Users\m-gri\.platformio\packages\framework-arduinoespressif8266\libraries\ESP8266WebServer\src/ESP8266WebServer.h:349,
                 from src\handler\abstract_handler.h:4,
                 from src\handler\flippie_handler.h:4,
                 from src\handler\flippie_handler.cpp:1:
C:\Users\m-gri\.platformio\packages\framework-arduinoespressif8266\libraries\ESP8266WebServer\src/detail/RequestHandlersImpl.h: In function 'String esp8266webserver::calcETag(fs::FS&, const String&)':
C:\Users\m-gri\.platformio\packages\framework-arduinoespressif8266\libraries\ESP8266WebServer\src/detail/RequestHandlersImpl.h:27:21: error: 'base64' has
not been declared
   27 |     result = "\"" + base64::encode(md5_buf, 16, false) + "\"";
      |                     ^~~~~~
In file included from C:\Users\m-gri\.platformio\packages\framework-arduinoespressif8266\libraries\ESP8266WebServer\src/ESP8266WebServer.h:349,
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

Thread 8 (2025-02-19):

I don't get it: Why TWO lines to control the rows?

wklenk, 2025-02-19:
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

Sorry, I don't get it.
If line a is used to control the column in a flip dot matrix (maybe from column 1 to 28), why cannot lines B and C get directly connected?
What should happen? They could be set to +24V, GND or no voltage state at all.
What am I missing?

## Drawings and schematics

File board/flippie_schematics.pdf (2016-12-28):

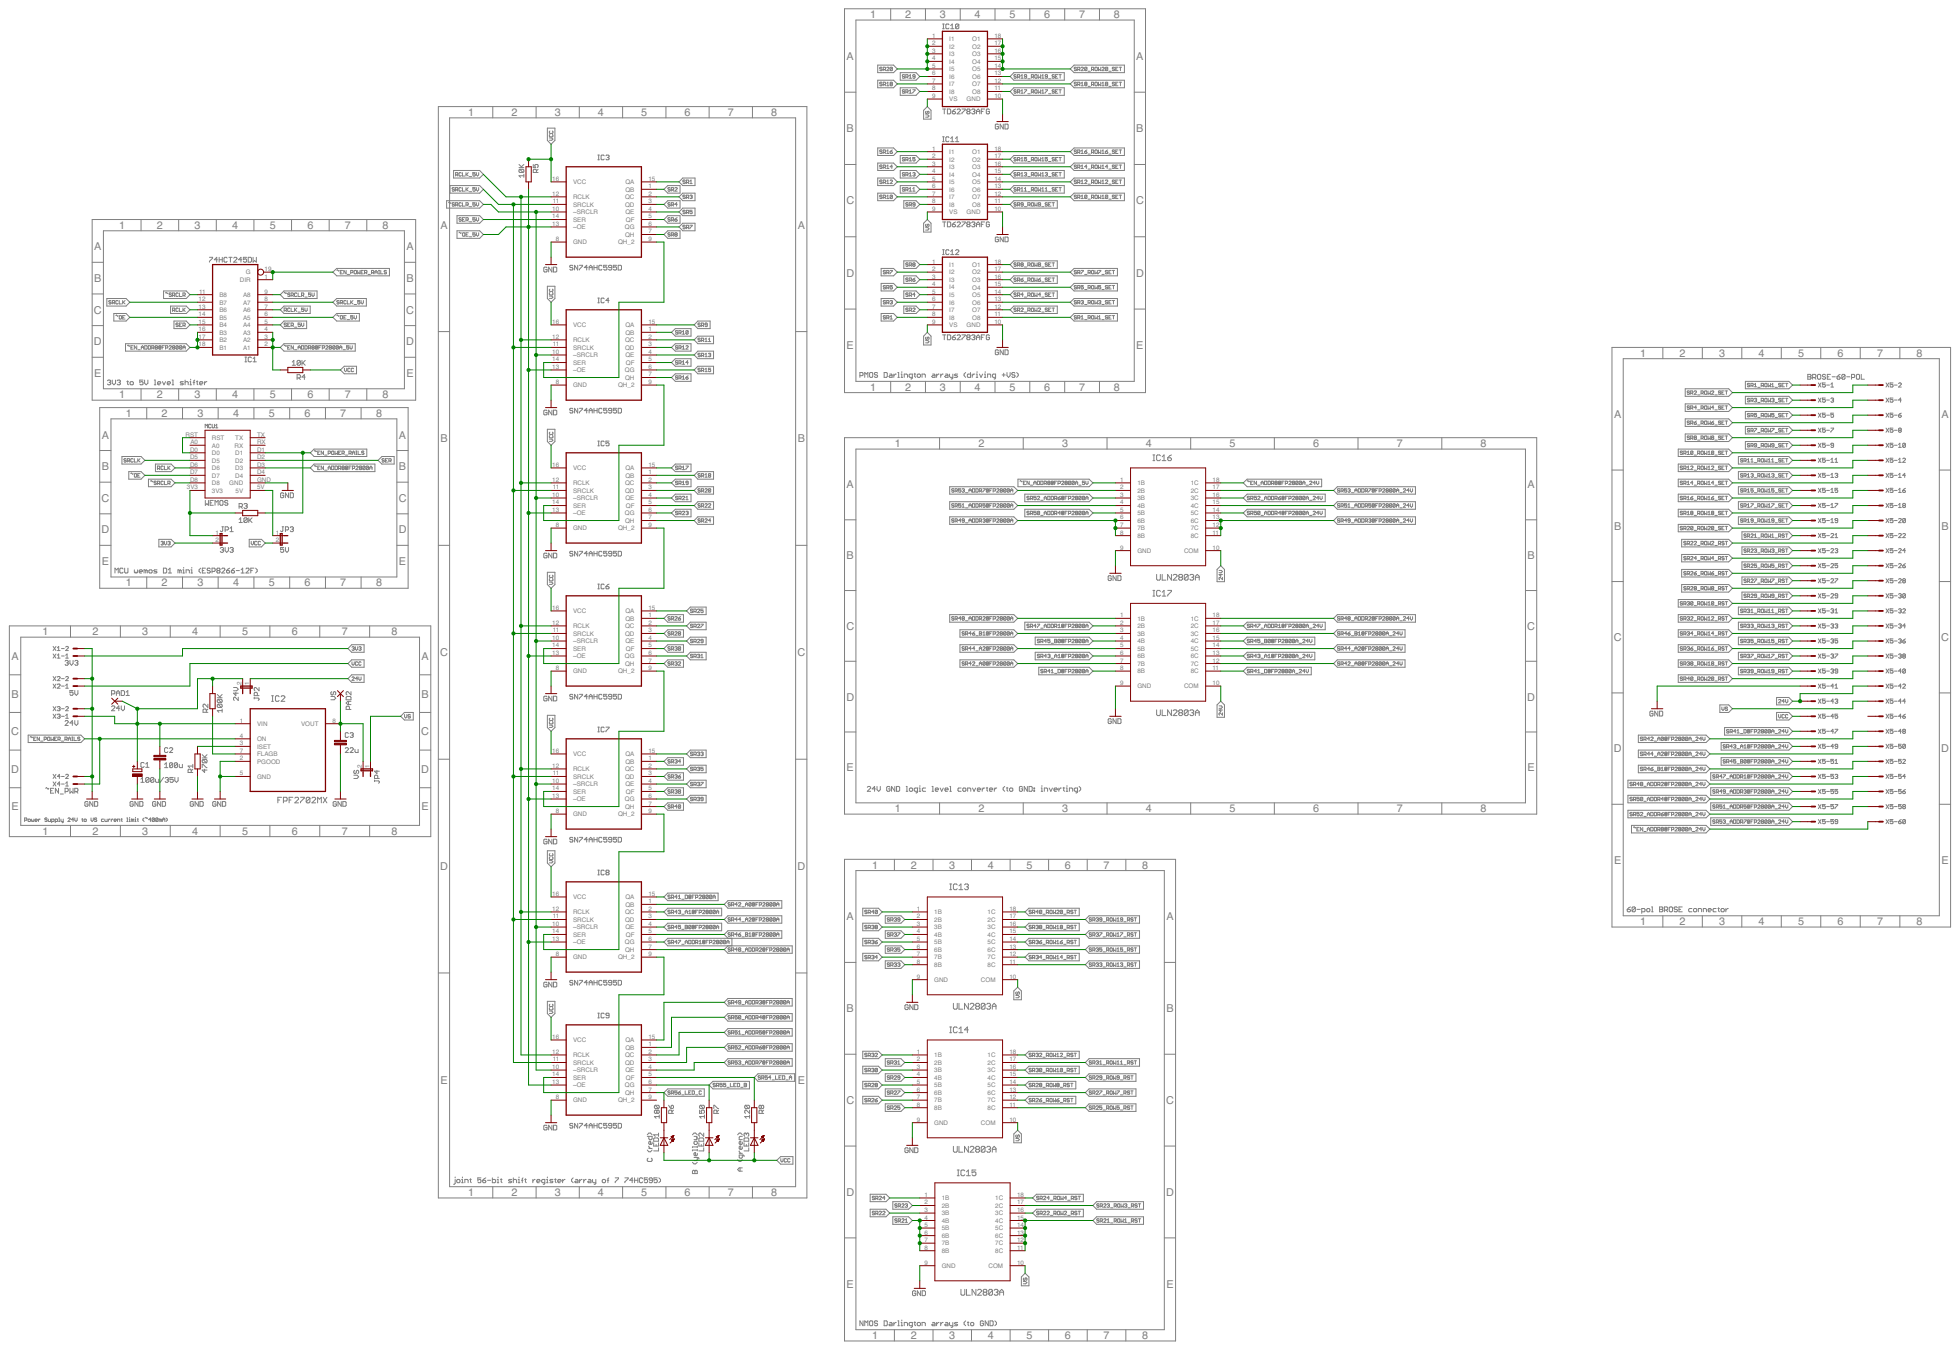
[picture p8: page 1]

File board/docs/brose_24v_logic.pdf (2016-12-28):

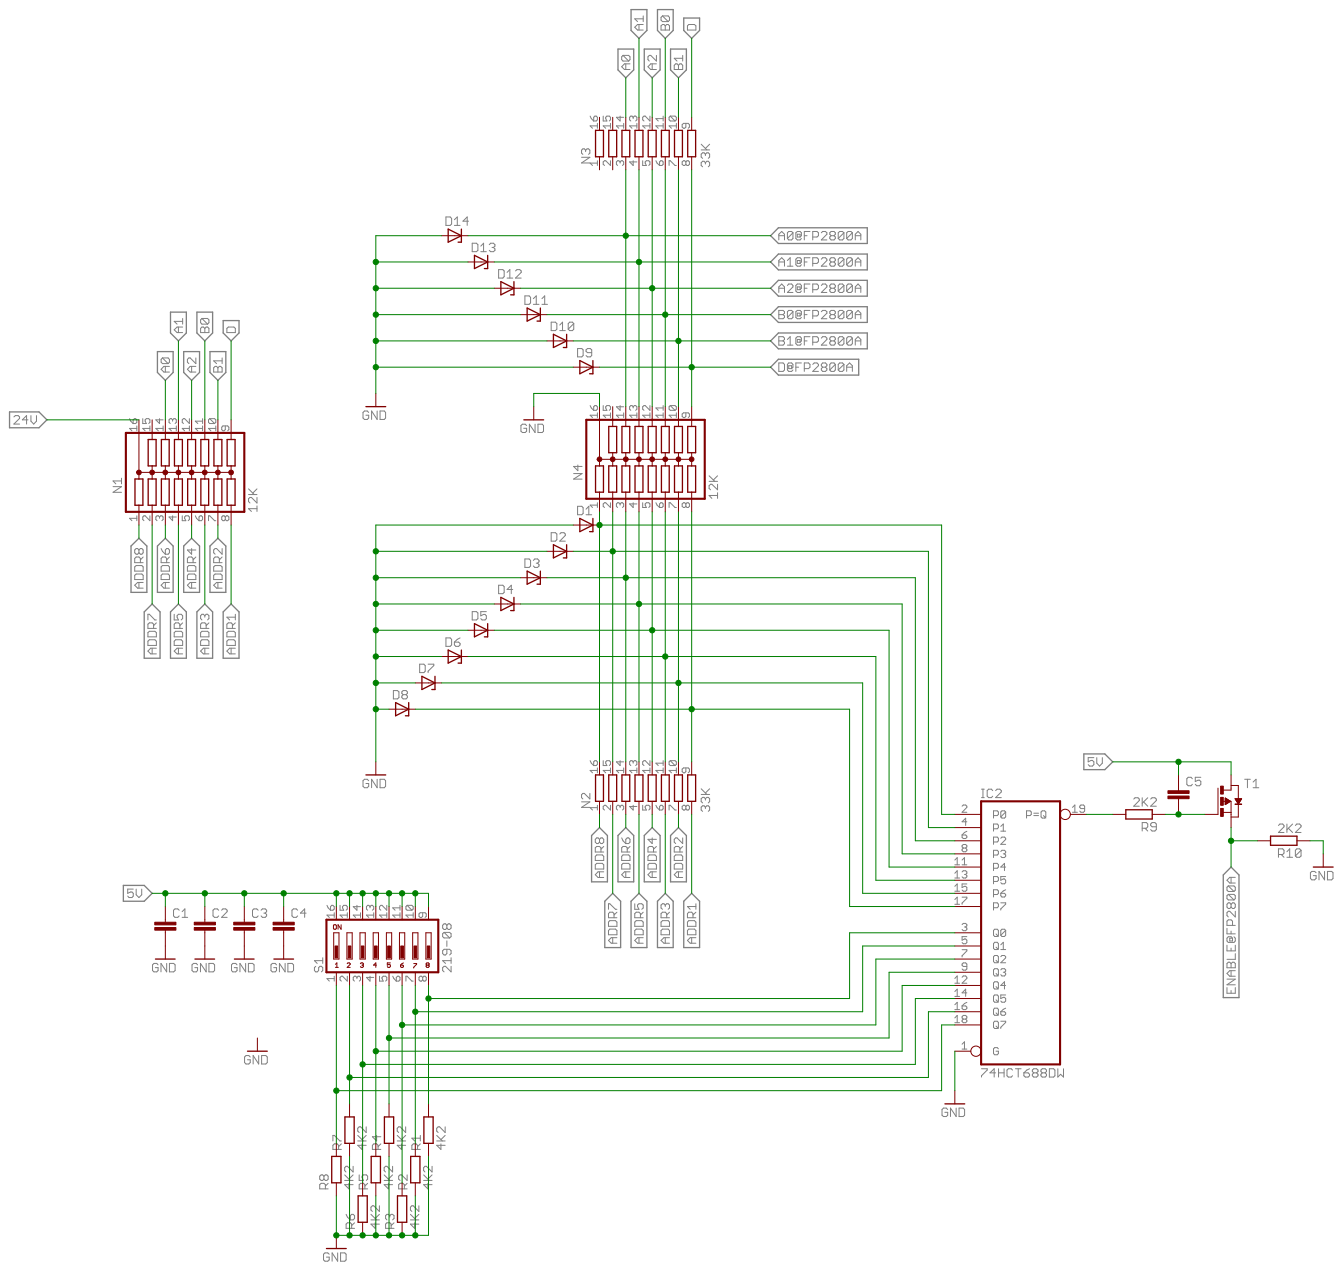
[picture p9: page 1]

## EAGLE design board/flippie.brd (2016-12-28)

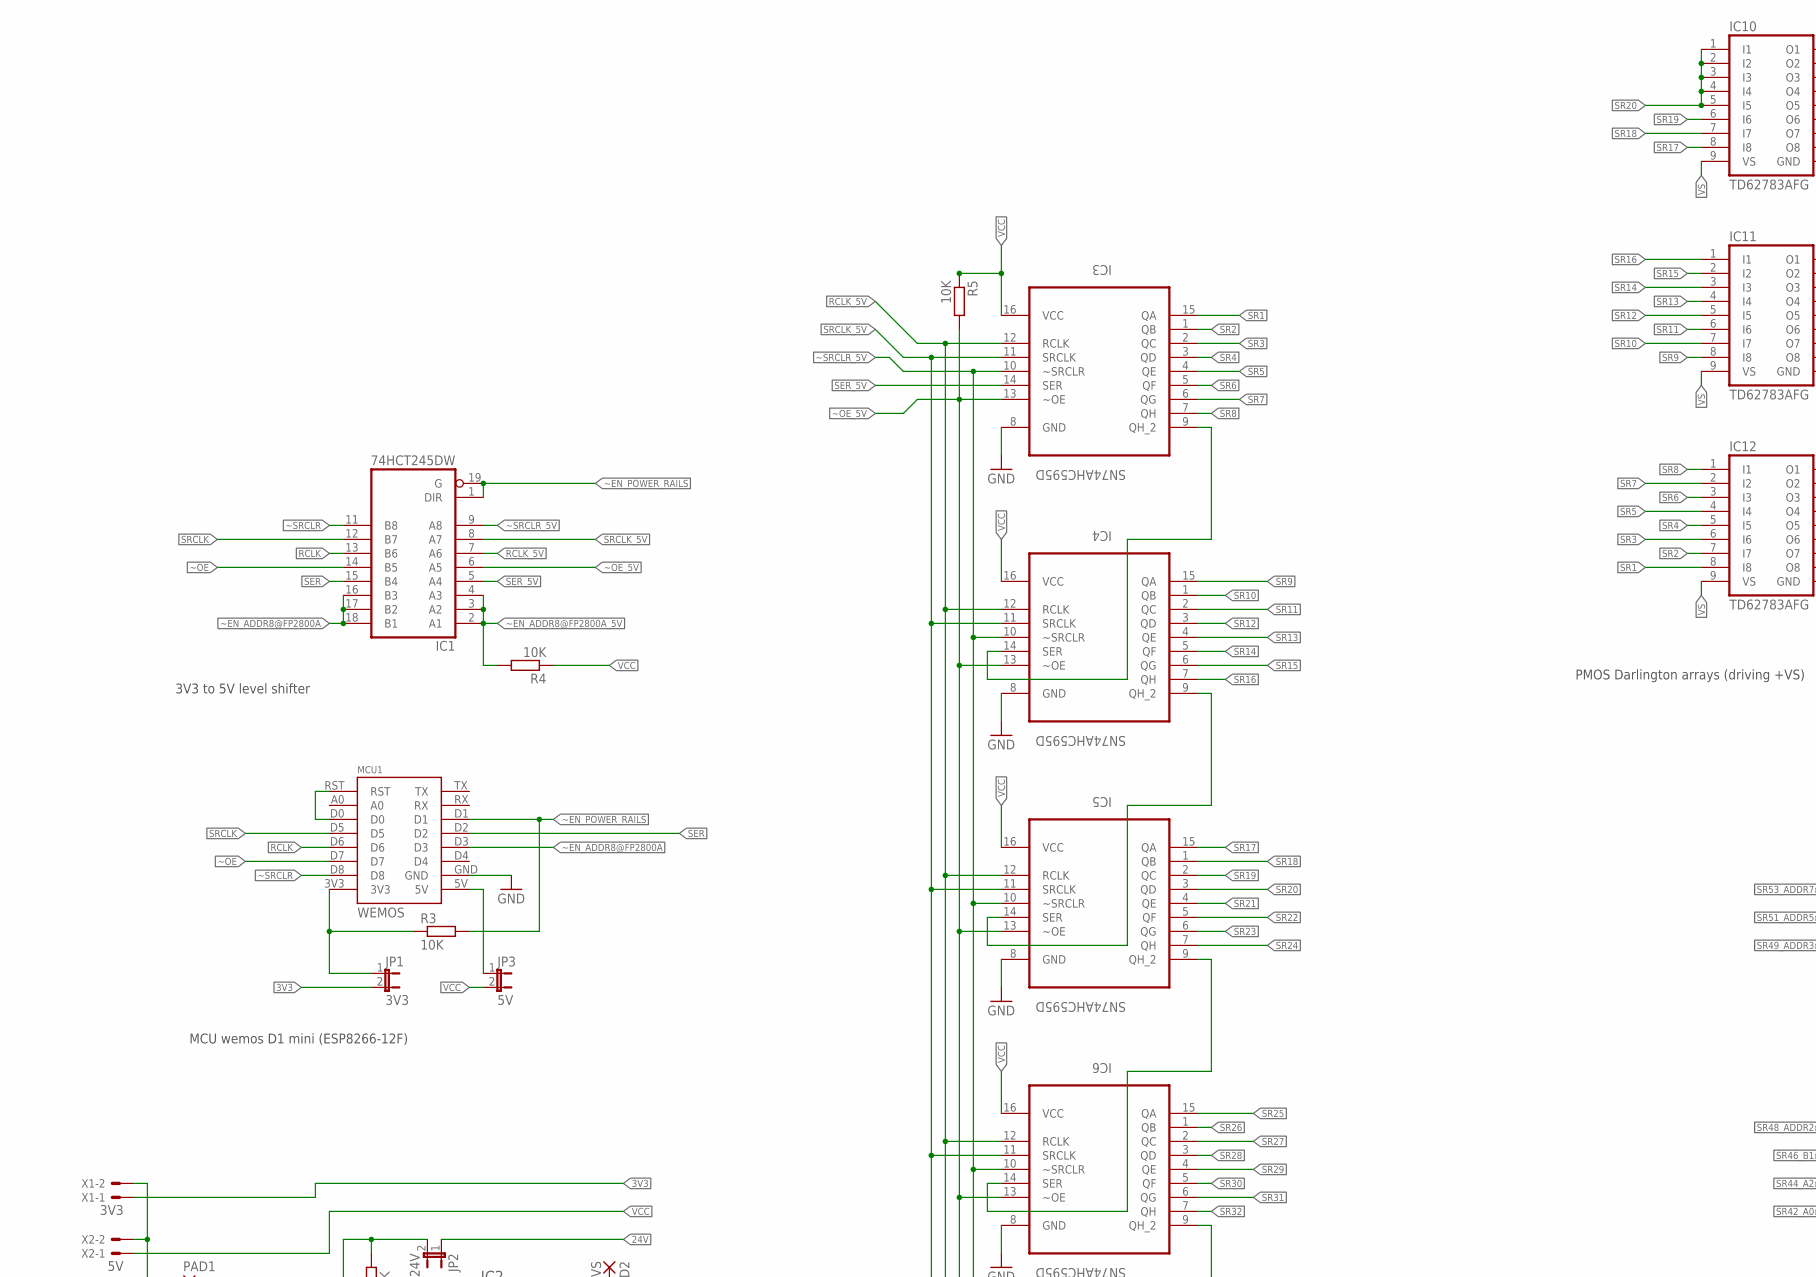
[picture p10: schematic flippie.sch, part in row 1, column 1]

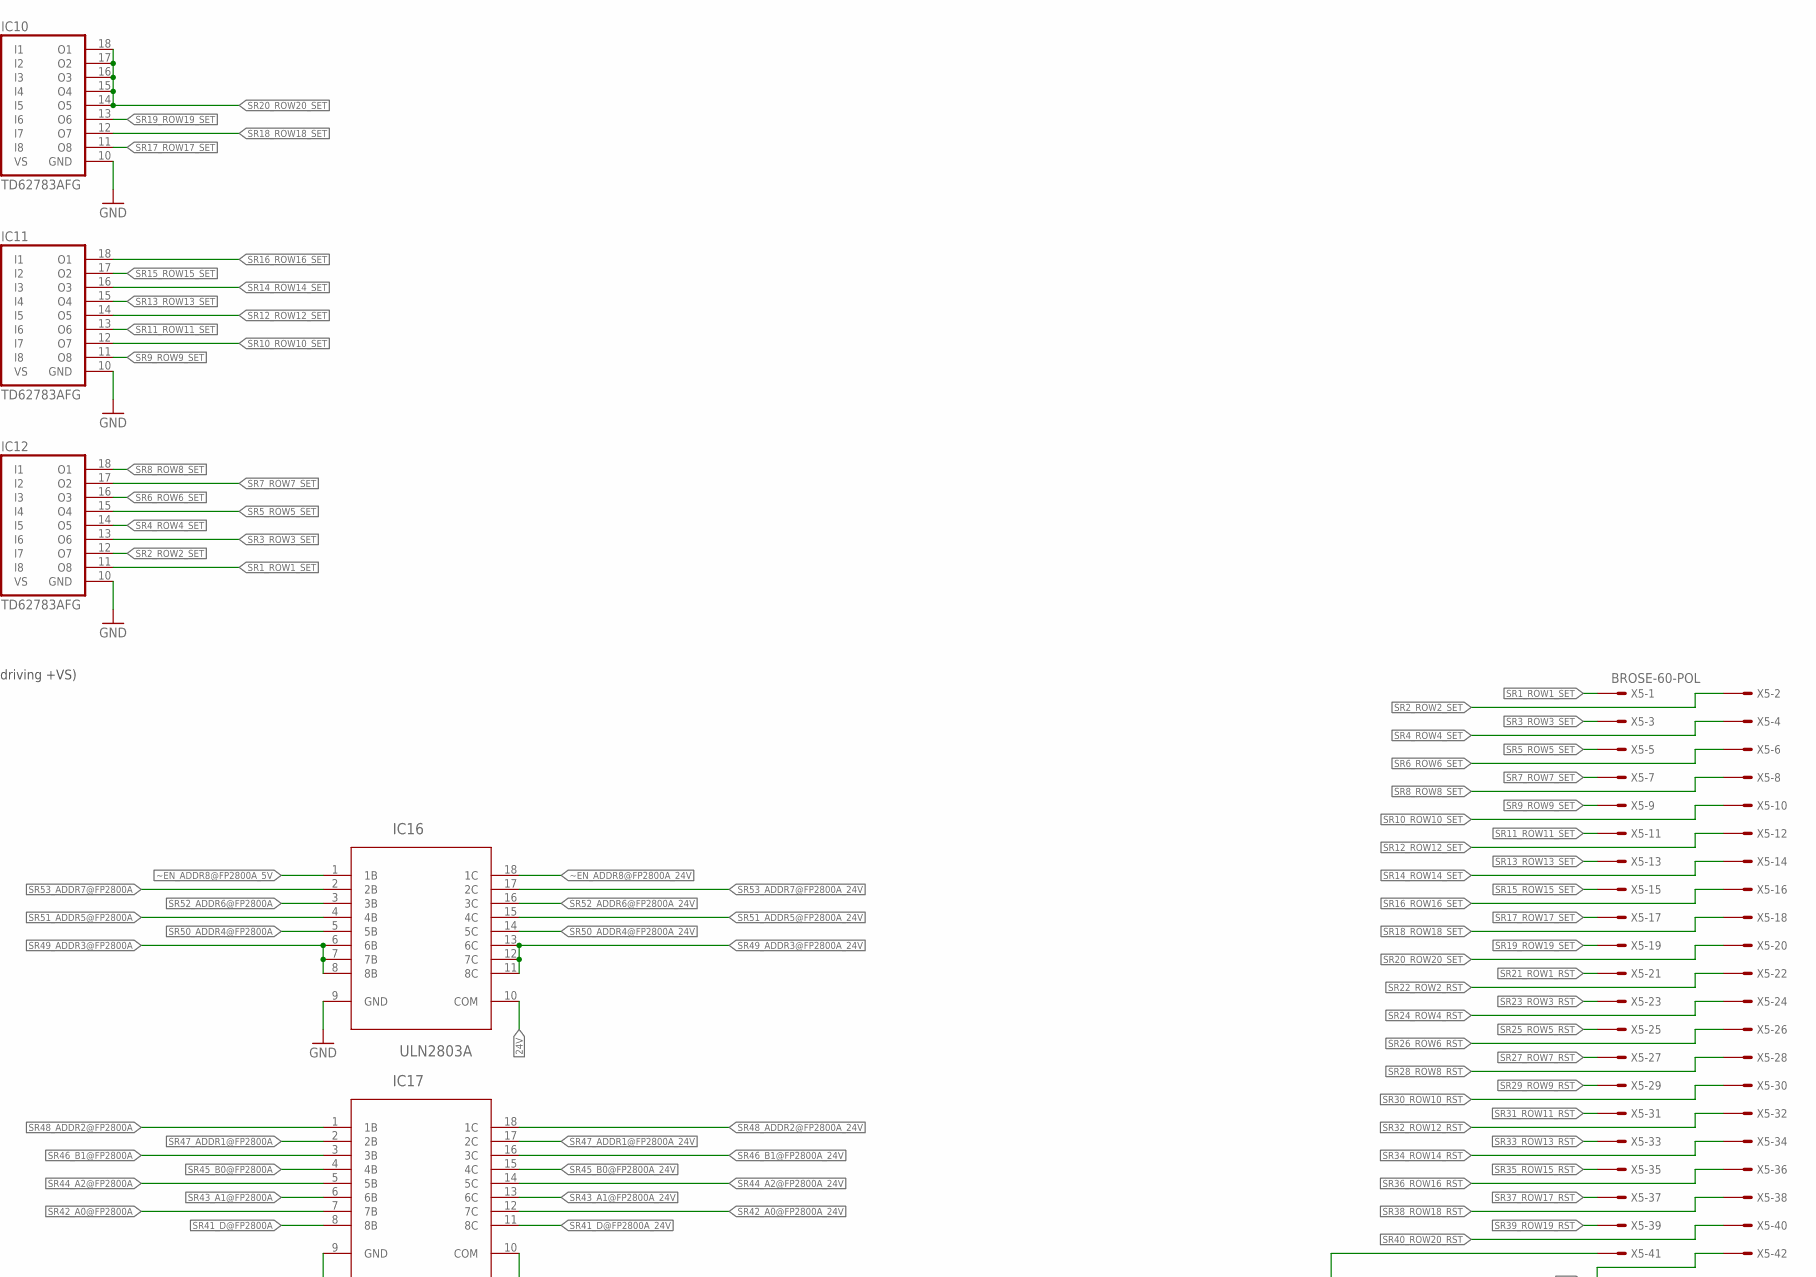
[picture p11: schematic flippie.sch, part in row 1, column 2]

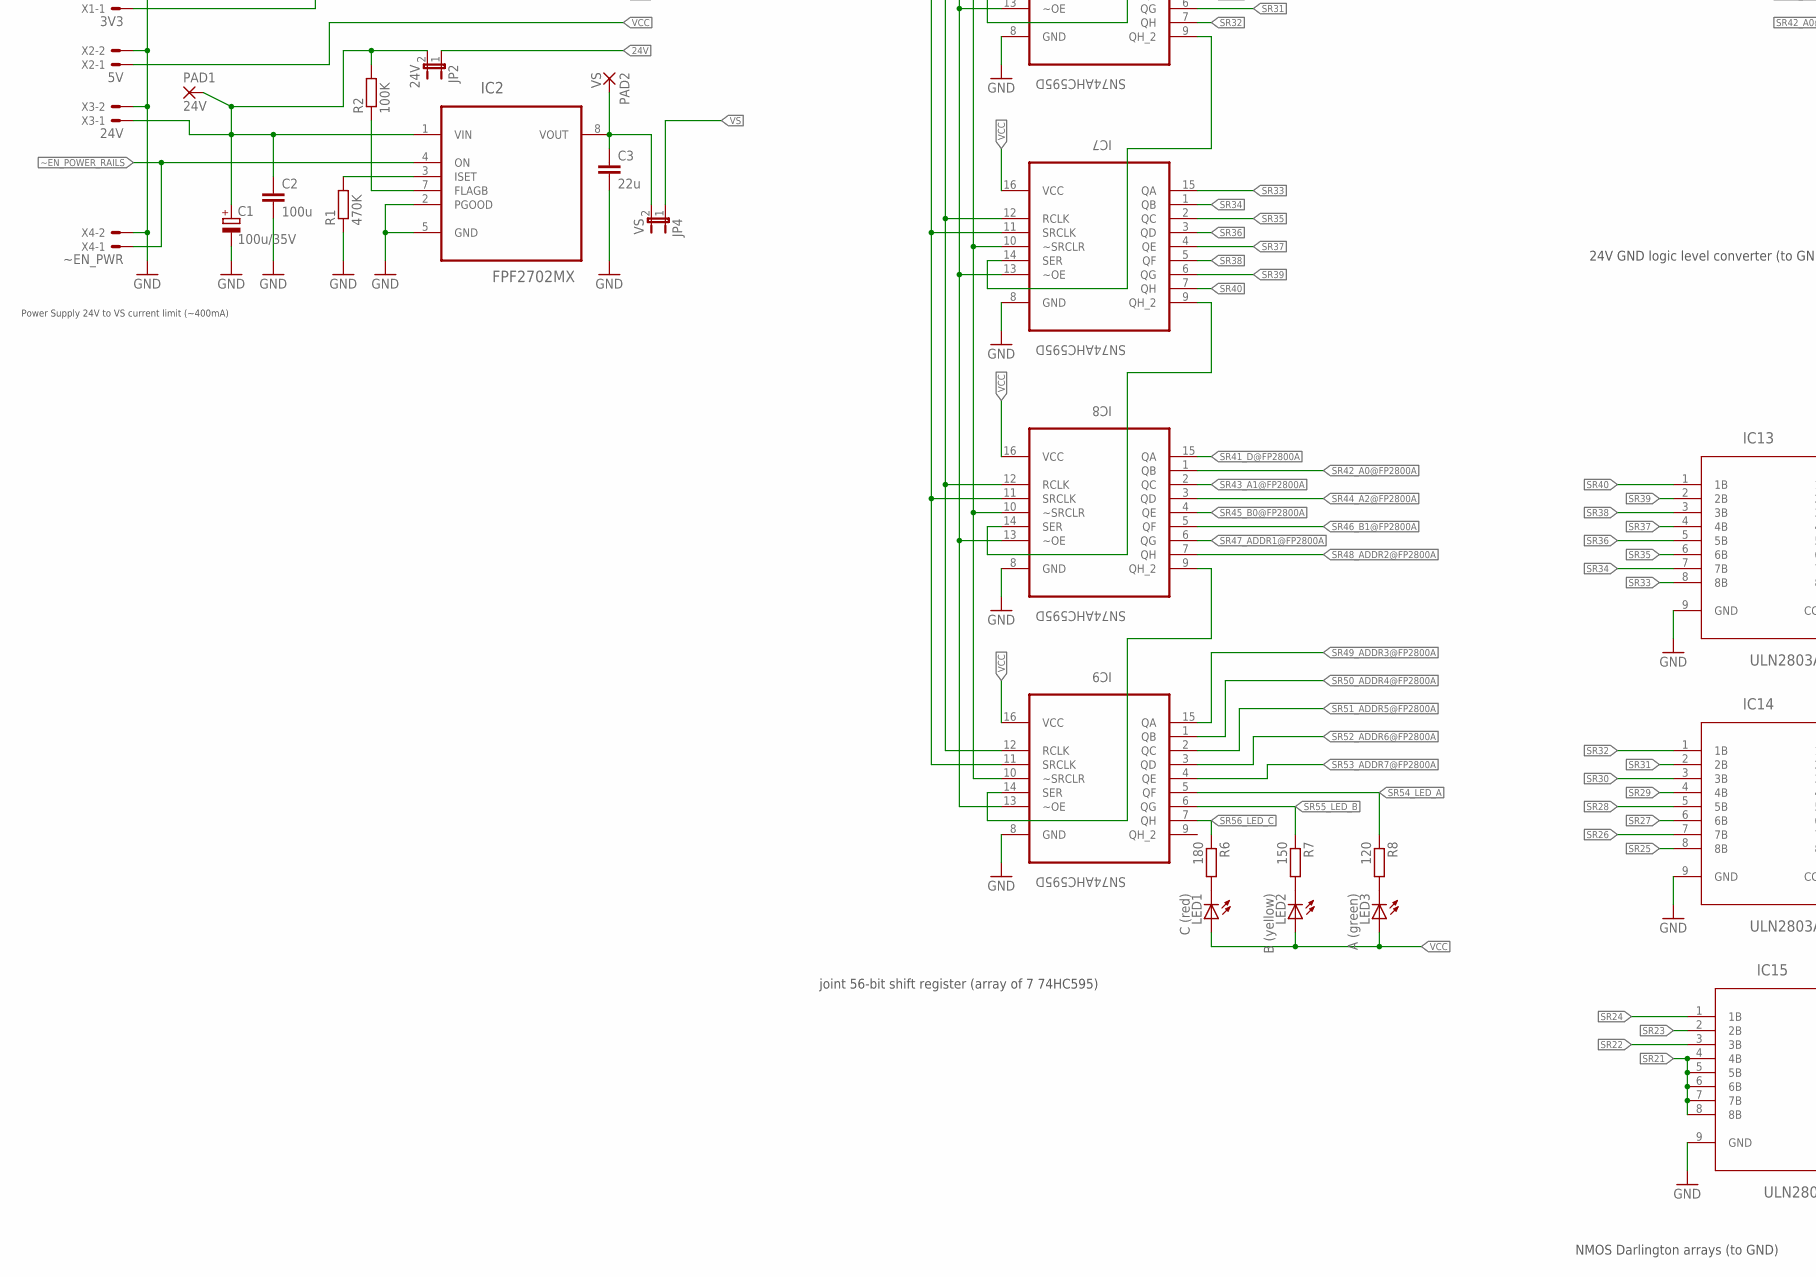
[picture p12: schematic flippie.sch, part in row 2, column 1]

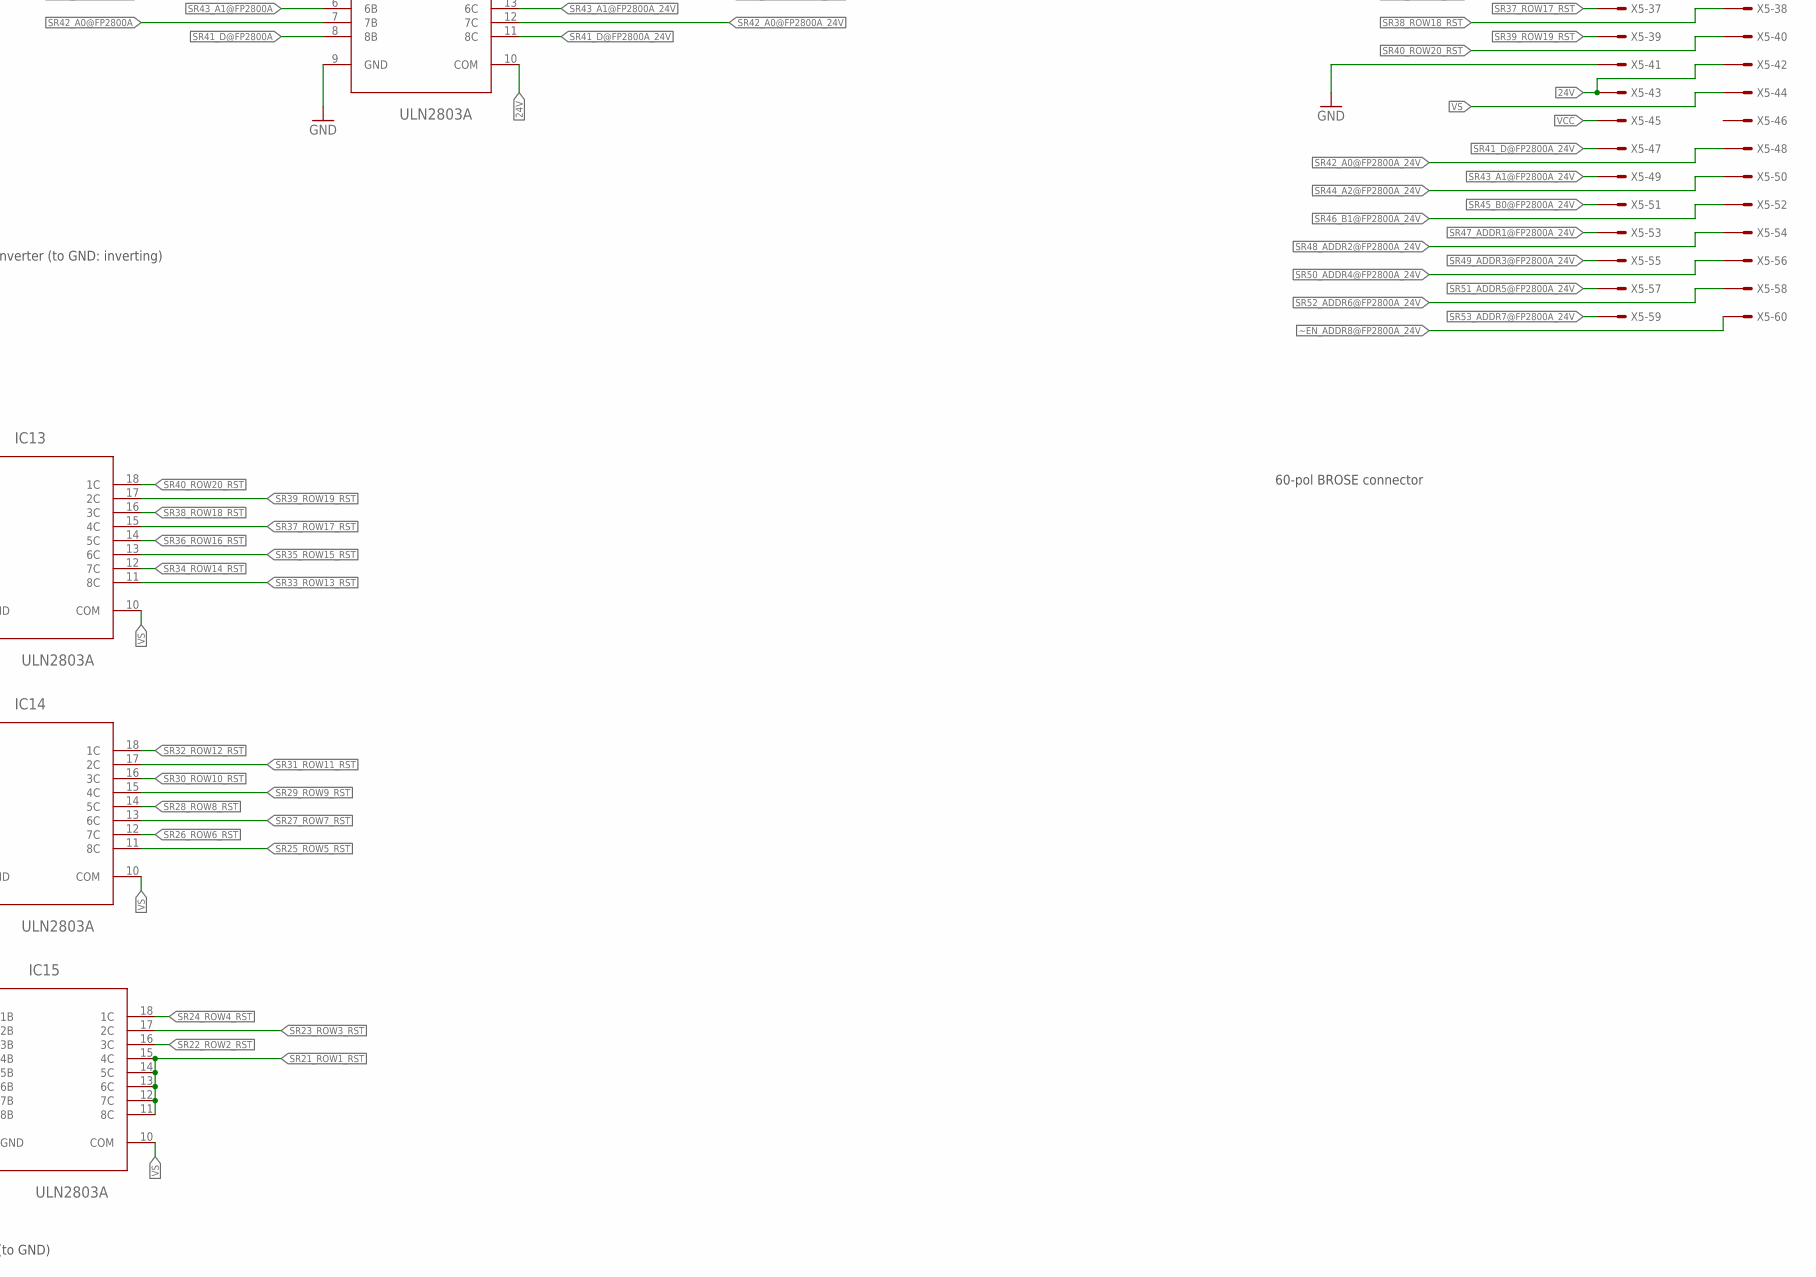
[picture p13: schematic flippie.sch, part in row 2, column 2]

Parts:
C1: 100u/35V; PANASONIC_E
C2: 100u; C1206
C3: 22u; C1206
IC1: 74HCT245DW; SO20W
IC2: FPF2702MX; SOIC127P600X175-8N
IC3, IC4, IC5, IC6, IC7, IC8, IC9: SN74AHC595D; SOIC127P600X175-16N
IC10, IC11, IC12: TD62783AFG; SO18W
IC13, IC14, IC15, IC16, IC17: ULN2803A; SOIC127P1030X265-18N
JP1: 3V3; JP1
JP2: 24V; JP1
JP3: 5V; JP1
JP4: VS; JP1
LED1: C (red); 1206
LED2: B (yellow); 1206
LED3: A (green); 1206
MCU1: WEMOS
PAD1: 24V; 2,15/1,0
PAD2: VS; 2,15/1,0
R1: 470K; R1206
R2: 100K; R1206
R3, R4, R5: 10K; R1206
R6: 180; R1206
R7: 150; R1206
R8: 120; R1206
X1: 3V3; JST-XH-02-PACKAGE-LONG-PAD
X2: 5V; JST-XH-02-PACKAGE-LONG-PAD
X3: 24V; JST-XH-02-PACKAGE-LONG-PAD
X4: ~EN_PWR; JST-XH-02-PACKAGE-LONG-PAD
X5: BROSE-60-POL; 057-060-1

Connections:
3V3: JP1.2, X1.1
3V3_SW: JP1.1, MCU1.3V3, R3.1
24V: IC16.10 (COM), IC17.10 (COM), JP2.1, X5.42, X5.43
24V_SW: C1.+, C2.1, IC2.1 (VIN), JP2.2, PAD1.1, R2.2, X3.1
GND: C1.-, C2.2, C3.2, IC1.10 (GND), IC2.2 (PGOOD), IC2.5 (GND), IC3.8 (GND), IC4.8 (GND), IC5.8 (GND), IC6.8 (GND), IC7.8 (GND), IC8.8 (GND), IC9.8 (GND), IC10.10 (GND), IC11.10 (GND), IC12.10 (GND), IC13.9 (GND), IC14.9 (GND), IC15.9 (GND), IC16.9 (GND), IC17.9 (GND), MCU1.GND, R1.1, X1.2, X2.2, X3.2, X4.2, X5.41
unnamed: IC6.9 (QH_2), IC7.14 (SER)
unnamed: IC2.7 (FLAGB), R2.1
unnamed: IC2.3 (ISET), R1.2
unnamed: LED1.C, R6.2
unnamed: IC8.9 (QH_2), IC9.14 (SER)
unnamed: MCU1.D0, MCU1.RST
unnamed: IC4.9 (QH_2), IC5.14 (SER)
unnamed: LED2.C, R7.2
unnamed: IC5.9 (QH_2), IC6.14 (SER)
unnamed: LED3.C, R8.2
unnamed: IC3.9 (QH_2), IC4.14 (SER)
unnamed: IC7.9 (QH_2), IC8.14 (SER)
RCLK: IC1.13 (B6), MCU1.D6
RCLK_5V: IC1.7 (A6), IC3.12 (RCLK), IC4.12 (RCLK), IC5.12 (RCLK), IC6.12 (RCLK), IC7.12 (RCLK), IC8.12 (RCLK), IC9.12 (RCLK)
SER: IC1.15 (B4), MCU1.D2
SER_5V: IC1.5 (A4), IC3.14 (SER)
SR1: IC3.15 (QA), IC12.8 (I8)
SR1_ROW1_SET: IC12.11 (O8), X5.1
SR2: IC3.1 (QB), IC12.7 (I7)
SR2_ROW2_SET: IC12.12 (O7), X5.2
SR3: IC3.2 (QC), IC12.6 (I6)
SR3_ROW3_SET: IC12.13 (O6), X5.3
SR4: IC3.3 (QD), IC12.5 (I5)
SR4_ROW4_SET: IC12.14 (O5), X5.4
SR5: IC3.4 (QE), IC12.4 (I4)
SR5_ROW5_SET: IC12.15 (O4), X5.5
SR6: IC3.5 (QF), IC12.3 (I3)
SR6_ROW6_SET: IC12.16 (O3), X5.6
SR7: IC3.6 (QG), IC12.2 (I2)
SR7_ROW7_SET: IC12.17 (O2), X5.7
SR8: IC3.7 (QH), IC12.1 (I1)
SR8_ROW8_SET: IC12.18 (O1), X5.8
SR9: IC4.15 (QA), IC11.8 (I8)
SR9_ROW9_SET: IC11.11 (O8), X5.9
SR10: IC4.1 (QB), IC11.7 (I7)
SR10_ROW10_SET: IC11.12 (O7), X5.10
SR11: IC4.2 (QC), IC11.6 (I6)
SR11_ROW11_SET: IC11.13 (O6), X5.11
SR12: IC4.3 (QD), IC11.5 (I5)
SR12_ROW12_SET: IC11.14 (O5), X5.12
SR13: IC4.4 (QE), IC11.4 (I4)
SR13_ROW13_SET: IC11.15 (O4), X5.13
SR14: IC4.5 (QF), IC11.3 (I3)
SR14_ROW14_SET: IC11.16 (O3), X5.14
SR15: IC4.6 (QG), IC11.2 (I2)
SR15_ROW15_SET: IC11.17 (O2), X5.15
SR16: IC4.7 (QH), IC11.1 (I1)
SR16_ROW16_SET: IC11.18 (O1), X5.16
SR17: IC5.15 (QA), IC10.8 (I8)
SR17_ROW17_SET: IC10.11 (O8), X5.17
SR18: IC5.1 (QB), IC10.7 (I7)
SR18_ROW18_SET: IC10.12 (O7), X5.18
SR19: IC5.2 (QC), IC10.6 (I6)
SR19_ROW19_SET: IC10.13 (O6), X5.19
SR20: IC5.3 (QD), IC10.1 (I1), IC10.2 (I2), IC10.3 (I3), IC10.4 (I4), IC10.5 (I5)
SR20_ROW20_SET: IC10.14 (O5), IC10.15 (O4), IC10.16 (O3), IC10.17 (O2), IC10.18 (O1), X5.20
SR21: IC5.4 (QE), IC15.4 (4B), IC15.5 (5B), IC15.6 (6B), IC15.7 (7B), IC15.8 (8B)
SR21_ROW1_RST: IC15.11 (8C), IC15.12 (7C), IC15.13 (6C), IC15.14 (5C), IC15.15 (4C), X5.21
SR22: IC5.5 (QF), IC15.3 (3B)
SR22_ROW2_RST: IC15.16 (3C), X5.22
SR23: IC5.6 (QG), IC15.2 (2B)
SR23_ROW3_RST: IC15.17 (2C), X5.23
SR24: IC5.7 (QH), IC15.1 (1B)
SR24_ROW4_RST: IC15.18 (1C), X5.24
SR25: IC6.15 (QA), IC14.8 (8B)
SR25_ROW5_RST: IC14.11 (8C), X5.25
SR26: IC6.1 (QB), IC14.7 (7B)
SR26_ROW6_RST: IC14.12 (7C), X5.26
SR27: IC6.2 (QC), IC14.6 (6B)
SR27_ROW7_RST: IC14.13 (6C), X5.27
SR28: IC6.3 (QD), IC14.5 (5B)
SR28_ROW8_RST: IC14.14 (5C), X5.28
SR29: IC6.4 (QE), IC14.4 (4B)
SR29_ROW9_RST: IC14.15 (4C), X5.29
SR30: IC6.5 (QF), IC14.3 (3B)
SR30_ROW10_RST: IC14.16 (3C), X5.30
SR31: IC6.6 (QG), IC14.2 (2B)
SR31_ROW11_RST: IC14.17 (2C), X5.31
SR32: IC6.7 (QH), IC14.1 (1B)
SR32_ROW12_RST: IC14.18 (1C), X5.32
SR33: IC7.15 (QA), IC13.8 (8B)
SR33_ROW13_RST: IC13.11 (8C), X5.33
SR34: IC7.1 (QB), IC13.7 (7B)
SR34_ROW14_RST: IC13.12 (7C), X5.34
SR35: IC7.2 (QC), IC13.6 (6B)
SR35_ROW15_RST: IC13.13 (6C), X5.35
SR36: IC7.3 (QD), IC13.5 (5B)
SR36_ROW16_RST: IC13.14 (5C), X5.36
SR37: IC7.4 (QE), IC13.4 (4B)
SR37_ROW17_RST: IC13.15 (4C), X5.37
SR38: IC7.5 (QF), IC13.3 (3B)
SR38_ROW18_RST: IC13.16 (3C), X5.38
SR39: IC7.6 (QG), IC13.2 (2B)
SR39_ROW19_RST: IC13.17 (2C), X5.39
SR40: IC7.7 (QH), IC13.1 (1B)
SR40_ROW20_RST: IC13.18 (1C), X5.40
SR41_D@FP2800A: IC8.15 (QA), IC17.8 (8B)
SR41_D@FP2800A_24V: IC17.11 (8C), X5.47
SR42_A0@FP2800A: IC8.1 (QB), IC17.7 (7B)
SR42_A0@FP2800A_24V: IC17.12 (7C), X5.48
SR43_A1@FP2800A: IC8.2 (QC), IC17.6 (6B)
SR43_A1@FP2800A_24V: IC17.13 (6C), X5.49
SR44_A2@FP2800A: IC8.3 (QD), IC17.5 (5B)
SR44_A2@FP2800A_24V: IC17.14 (5C), X5.50
SR45_B0@FP2800A: IC8.4 (QE), IC17.4 (4B)
SR45_B0@FP2800A_24V: IC17.15 (4C), X5.51
SR46_B1@FP2800A: IC8.5 (QF), IC17.3 (3B)
SR46_B1@FP2800A_24V: IC17.16 (3C), X5.52
SR47_ADDR1@FP2800A: IC8.6 (QG), IC17.2 (2B)
SR47_ADDR1@FP2800A_24V: IC17.17 (2C), X5.53
SR48_ADDR2@FP2800A: IC8.7 (QH), IC17.1 (1B)
SR48_ADDR2@FP2800A_24V: IC17.18 (1C), X5.54
SR49_ADDR3@FP2800A: IC9.15 (QA), IC16.6 (6B), IC16.7 (7B), IC16.8 (8B)
SR49_ADDR3@FP2800A_24V: IC16.11 (8C), IC16.12 (7C), IC16.13 (6C), X5.55
SR50_ADDR4@FP2800A: IC9.1 (QB), IC16.5 (5B)
SR50_ADDR4@FP2800A_24V: IC16.14 (5C), X5.56
SR51_ADDR5@FP2800A: IC9.2 (QC), IC16.4 (4B)
SR51_ADDR5@FP2800A_24V: IC16.15 (4C), X5.57
SR52_ADDR6@FP2800A: IC9.3 (QD), IC16.3 (3B)
SR52_ADDR6@FP2800A_24V: IC16.16 (3C), X5.58
SR53_ADDR7@FP2800A: IC9.4 (QE), IC16.2 (2B)
SR53_ADDR7@FP2800A_24V: IC16.17 (2C), X5.59
SR54_LED_A: IC9.5 (QF), R8.1
SR55_LED_B: IC9.6 (QG), R7.1
SR56_LED_C: IC9.7 (QH), R6.1
SRCLK: IC1.12 (B7), MCU1.D5
SRCLK_5V: IC1.8 (A7), IC3.11 (SRCLK), IC4.11 (SRCLK), IC5.11 (SRCLK), IC6.11 (SRCLK), IC7.11 (SRCLK), IC8.11 (SRCLK), IC9.11 (SRCLK)
VCC: IC1.20 (VCC), IC3.16 (VCC), IC4.16 (VCC), IC5.16 (VCC), IC6.16 (VCC), IC7.16 (VCC), IC8.16 (VCC), IC9.16 (VCC), JP3.2, LED1.A, LED2.A, LED3.A, R4.1, R5.1, X2.1, X5.45
VCC_SW: JP3.1, MCU1.5V
VS: IC10.9 (VS), IC11.9 (VS), IC12.9 (VS), IC13.10 (COM), IC14.10 (COM), IC15.10 (COM), JP4.1, X5.44
VS_SW: C3.1, IC2.8 (VOUT), JP4.2, PAD2.1
~EN_ADDR8@FP2800A: IC1.16 (B3), IC1.17 (B2), IC1.18 (B1), MCU1.D3
~EN_ADDR8@FP2800A_5V: IC1.2 (A1), IC1.3 (A2), IC1.4 (A3), IC16.1 (1B), R4.2
~EN_ADDR8@FP2800A_24V: IC16.18 (1C), X5.60
~EN_POWER_RAILS: IC1.1 (DIR), IC1.19 (G), IC2.4 (ON), MCU1.D1, R3.2, X4.1
~OE: IC1.14 (B5), MCU1.D7
~OE_5V: IC1.6 (A5), IC3.13 (~OE), IC4.13 (~OE), IC5.13 (~OE), IC6.13 (~OE), IC7.13 (~OE), IC8.13 (~OE), IC9.13 (~OE), R5.2
~SRCLR: IC1.11 (B8), MCU1.D8
~SRCLR_5V: IC1.9 (A8), IC3.10 (~SRCLR), IC4.10 (~SRCLR), IC5.10 (~SRCLR), IC6.10 (~SRCLR), IC7.10 (~SRCLR), IC8.10 (~SRCLR), IC9.10 (~SRCLR)

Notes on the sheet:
MCU wemos D1 mini (ESP8266-12F)
joint 56-bit shift register (array of 7 74HC595)
PMOS Darlington arrays (driving +VS)
NMOS Darlington arrays (to GND)
60-pol BROSE connector
Power Supply 24V to VS current limit (~400mA)
24V GND logic level converter (to GND: inverting)
3V3 to 5V level shifter

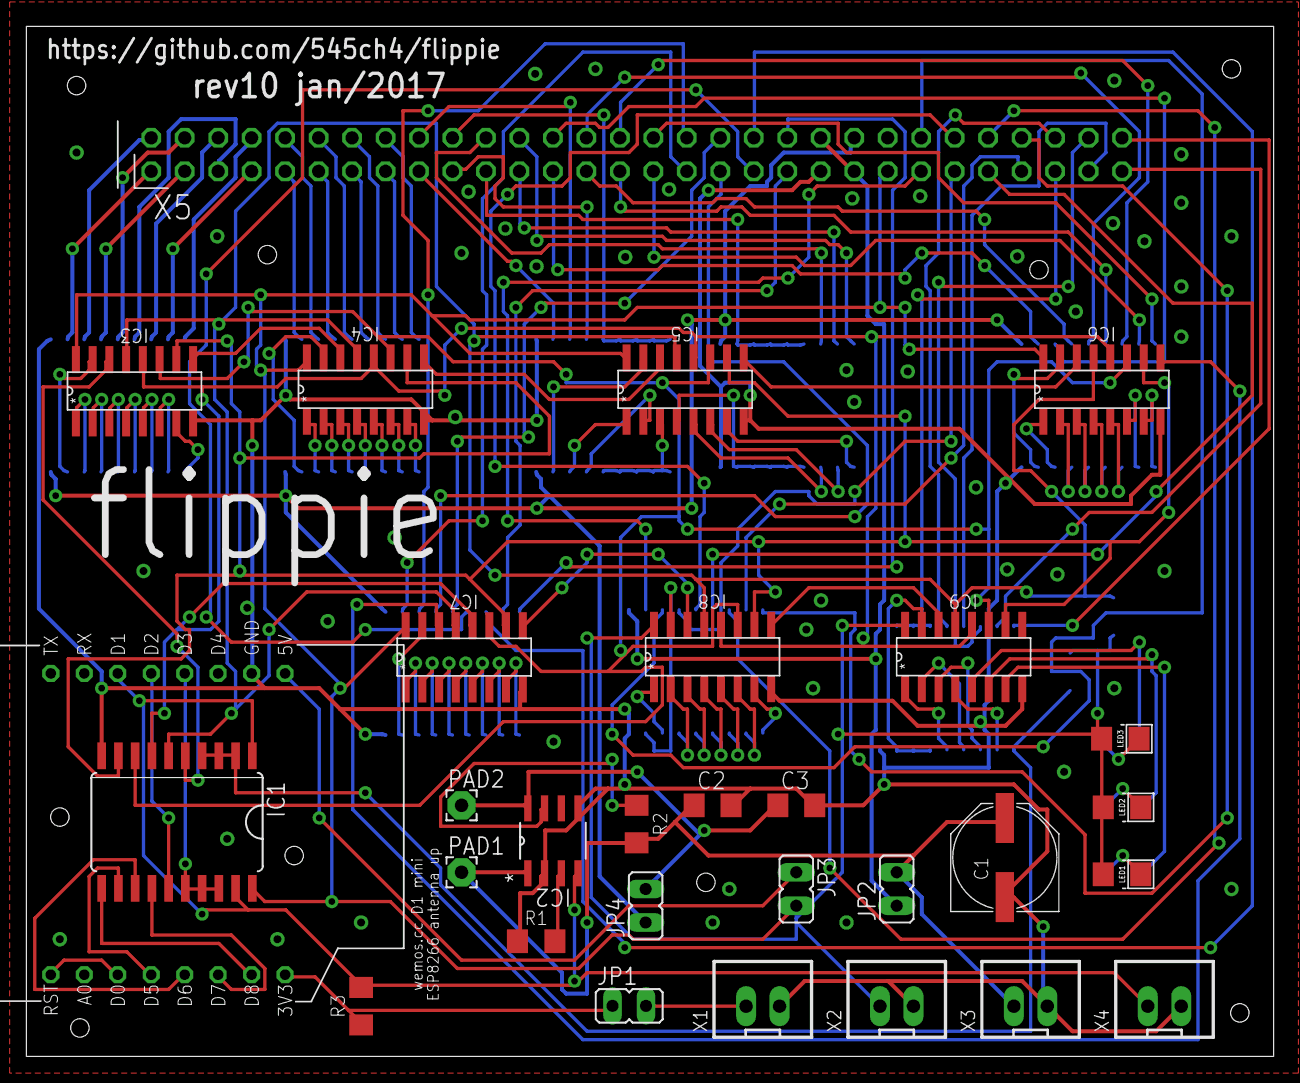
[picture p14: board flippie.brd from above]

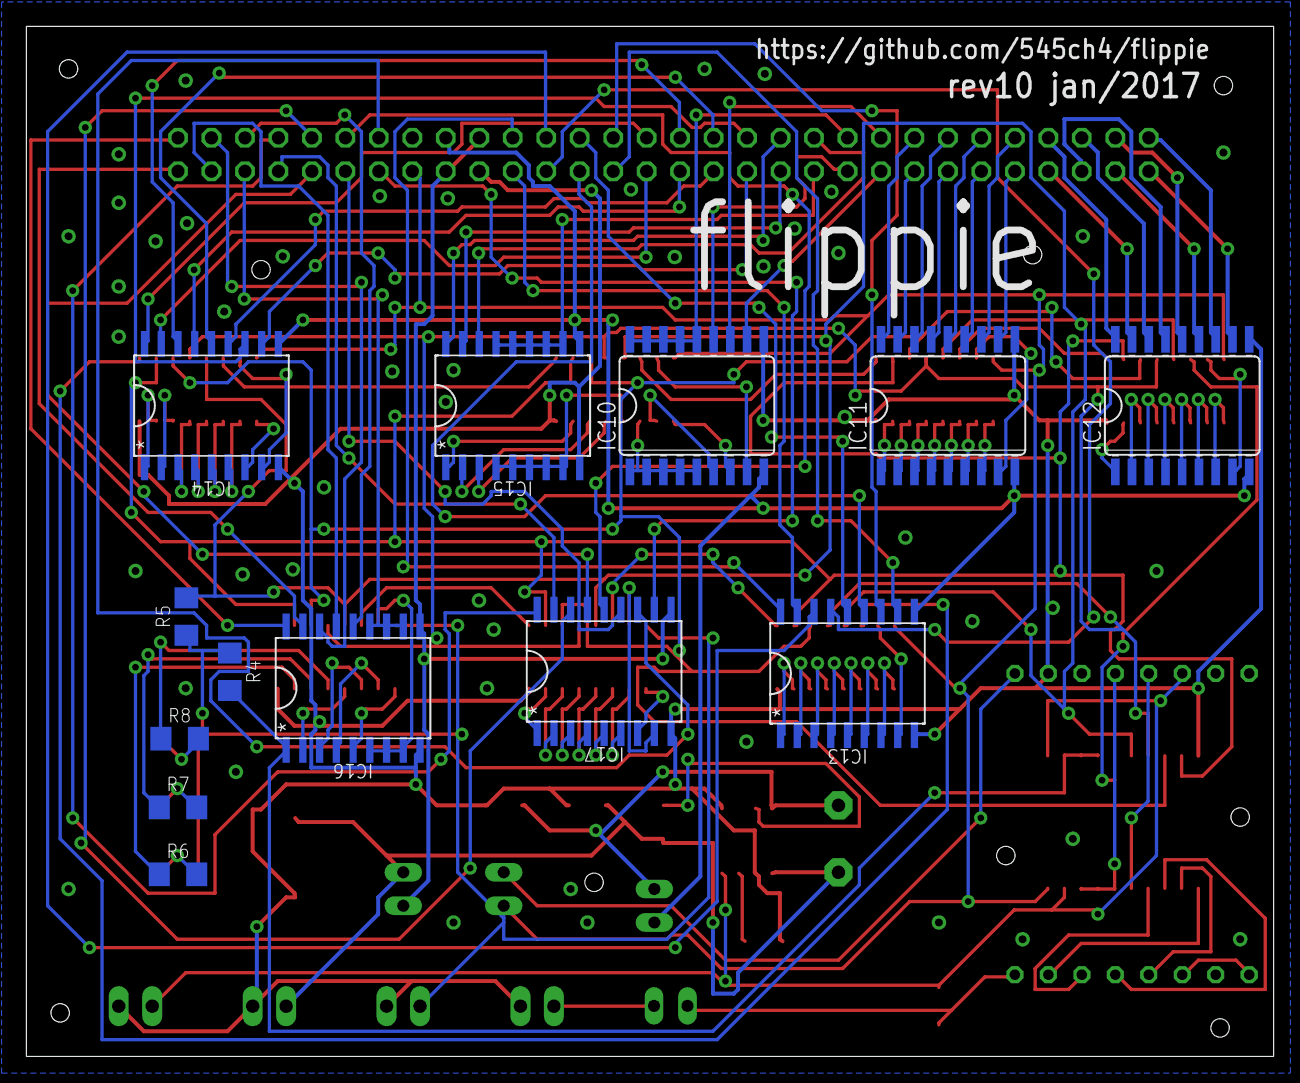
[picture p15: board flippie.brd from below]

Board: 2 copper layers, 94.6 x 78.2 mm, 43 parts (13 on the bottom side), 144 nets.

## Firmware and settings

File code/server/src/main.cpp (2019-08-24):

#include "debug.h"
#include <Arduino.h>
#include <ESP8266WebServer.h>
#include <ESP8266WiFi.h>
#include <NTPClient.h>
#include <WiFiClient.h>
#include <WiFiUdp.h>
//#include <ESP8266mDNS.h>
#include "../lib/functions.h"
#include "flippie_server.h"

// WiFiUDP ntpUDP;
// NTPClient timeClient(ntpUDP, "europe.pool.ntp.org", 3600, 60000);

ESP8266WebServer *server;

void setup(void) {
  Serial.begin(74880);
  Serial.println();
  Serial.println("Booting...");

  // TODO: What's the SSID of your WiFi?
  const char *ssid = "Camp2019-insecure";
  // TODO: What's the PASSWORD of your WiFi?
  const char *password = NULL;

  WiFi.mode(WIFI_AP_STA);
  WiFi.persistent(false);
  WiFi.disconnect(true);
  WiFi.begin(ssid, password);
  // WiFi.mode(WIFI_AP);
  // WiFi.softAP(ssid, NULL);

  // TODO: If you don't want to use DHCP, provide a static IP (and uncomment).
  // Othewise leave this commented.
  // IPAddress ip(192, 168, 1, 250);
  // IPAddress gateway(192, 168, 1, 250);
  // IPAddress subnet(255, 255, 255, 0);
  // WiFi.config(ip, gateway, subnet);

  // Wait for connection
  while (WiFi.status() != WL_CONNECTED) {
    delay(500);
    Serial.print(".");
  }
  Serial.printf("\nConnected to '%s'\n", ssid);
  Serial.printf("IP address: '%s'\n", WiFi.localIP().toString().c_str());
  //   timeClient.begin();
  //   timeClient.update();
  //   Serial.printf("Got new time '%s'\n",
  //   timeClient.getFormattedTime().c_str());

  //   MDNSResponder mdns;
  //   if (mdns.begin("flippie", WiFi.localIP())) {
  //      Serial.println("MDNS responder started");
  //   }

  server = new ESP8266WebServer(80);
  FlippieServer *flippie_server = new FlippieServer(server);
  server->begin();
  //   mdns.addService("http", "tcp", 80);

  Serial.printf("Ready! Open http://%s in your browser\n\n",
                WiFi.localIP().toString().c_str());
}

void loop(void) {
  server->handleClient();
  //   Serial.printf(".");
}

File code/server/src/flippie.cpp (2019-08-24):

#include "flippie.h"

Flippie::Flippie() {
  config = (flippie_t *)malloc(sizeof(flippie_t));
  unsigned char i;

  // TODO: How many modules does your display consists of?
  const unsigned char num_modules = 1;
  config->num_modules = num_modules;
  // TODO: What are the addresses (as byte) of the modules? (see DIP-switches at
  // each module)
  config->addresses = new unsigned char[num_modules]{1};
  // TODO: How many rows does your display have? (equal over all modules)
  config->num_rows = 16;
  // TODO: How many columns does each module of your display have? (same order
  // as the addresses)
  config->num_columns = new unsigned char[num_modules]{21};
  // TODO: Should LED C toggle on each shift-register firing?
  config->led_mode = LED_MODE_FLASHING;
  // TODO: Verbose outputs on serial line?
  config->verbose = true;

  // values below are specific to the flippie board - do not modify
  // shift-register config
  // SR1 - SR20 SET
  config->sr_row_set_pins = new unsigned char[BROSE_MAX_ROWS]{
      0, 1, 2, 3, 4, 5, 6, 7, 8, 9, 10, 11, 12, 13, 14, 15, 16, 17, 18, 19};
  // SR21 - SR40 RST
  config->sr_row_rst_pins =
      new unsigned char[BROSE_MAX_ROWS]{20, 21, 22, 23, 24, 25, 26, 27, 28, 29,
                                        30, 31, 32, 33, 34, 35, 36, 37, 38, 39};
  // SR41 D
  config->sr_d_pin = 40;
  // SR42 - SR46 A0-B1
  config->sr_column_code_pins =
      new unsigned char[FP2800A_COLUMN_CODE_LINES]{45, 44, 43, 42, 41};
  // SR47 - SR53 ADDR1-ADDR7
  config->sr_address_pins =
      new unsigned char[BROSE_ADDR_LINES]{46, 47, 48, 49, 50, 51, 52};
  // SR54 LED A
  config->sr_led_a_pin = 53;
  // SR55 LED B
  config->sr_led_b_pin = 54;
  // SR56 LED C
  config->sr_led_c_pin = 55;

  // shift-register input
  // 74*595 shift-register clear pin [normal:high, clear:low] (~MR, ~SRCLR,
  // ~SCLR, ~SCL)
  config->not_clear_pin = D8;
  // 74*595 shift-register clock pin (SH_CP, SRCLK, SCK)
  config->clock_pin = D5;
  // 74*595 shift-register storage register clock pin (latch) (ST_CP, RCLK, RCK)
  config->latch_pin = D6;
  // 74*595 shift-register output enable pin [normal:low, tristate output:high]
  // (~G, ~OE)
  config->not_output_enable_pin = D7;
  // 74*595 shift-register serial data input pin (DS, SER, A, SI)
  config->serial_data_pin = D2;

  // ~EN_POWER_RAILS pin (eg. ON pin at current limiter FPF2702MX circuit)
  config->not_enable_power_rails_pin = D1;

  // ~EN and ADDR8@FP2800A
  config->not_enable_pin = D3;

  if (config->verbose)
    Serial.println("Finished configure flippie.");

  // init fast bit-wise comparator array (int-sized)
  _int_bit_array = (unsigned int *)malloc(32 * sizeof(unsigned int));
  for (i = 0; i < 32; ++i) {
    _int_bit_array[i] = 1 << i;
  }
  // init fast bit-wise comparator array (byte-sized)
  _byte_bit_array =
      (unsigned char *)malloc(SHIFT_REGISTER_WIDTH * sizeof(unsigned char));
  for (i = 0; i < SHIFT_REGISTER_WIDTH; ++i) {
    _byte_bit_array[i] = 1 << i;
  }

  // initialze shift-register as NUMBER_OF_SHIFT_REGISTERS *
  // SHIFT_REGISTER_WIDTH
  _shift_register =
      (unsigned char *)calloc(NUMBER_OF_SHIFT_REGISTERS, SHIFT_REGISTER_WIDTH);

  // shift-register LED_A, LED_B and LED_C
  led_A_on = false;
  led_B_on = false;
  led_C_on = false;

  // define pins (not srPins) as outputs

  pinMode(config->not_output_enable_pin, OUTPUT);
  // tri-state all outputs of the shift-register
  digitalWrite(config->not_output_enable_pin, HIGH);

  pinMode(config->clock_pin, OUTPUT);
  digitalWrite(config->clock_pin, LOW);

  pinMode(config->serial_data_pin, OUTPUT);
  digitalWrite(config->serial_data_pin, LOW);

  pinMode(config->latch_pin, OUTPUT);
  digitalWrite(config->latch_pin, LOW);

  pinMode(config->not_clear_pin, OUTPUT);
  digitalWrite(config->not_clear_pin, HIGH);

  // don't enable FP2800A
  pinMode(config->not_enable_pin, OUTPUT);
  digitalWrite(config->not_enable_pin, HIGH);

  // reset shift-register
  digitalWrite(config->not_clear_pin, LOW);
  digitalWrite(config->not_clear_pin, HIGH);

  // enable all power rails
  pinMode(config->not_enable_power_rails_pin, OUTPUT);
  digitalWrite(config->not_enable_power_rails_pin, LOW);

  // enable all outputs of the shift-register
  digitalWrite(config->not_output_enable_pin, LOW);

  // disable internal LED
  digitalWrite(D4, HIGH);

  if (config->verbose)
    Serial.println("Finished defining and setting all output pins.");

  // init shift-register to LOW except flash LED_A, LED_B and LED_C three times
  for (i = 0; i < 3; ++i) {
    led_A_on = true;
    led_B_on = true;
    led_C_on = true;
    fire_shift_register(false);
    delay(100);
    led_A_on = false;
    led_B_on = false;
    led_C_on = false;
    fire_shift_register(false);
    delay(700);
  }
  if (config->led_mode == LED_MODE_FLASHING) {
    flashing_led_C_on = false;
  }

  if (config->verbose)
    Serial.println("\nFinished first test of shift-register.");

  // initialze _dots and _next_dots
  // array of rows => array of modules => columns are encoded bit-wise in an
  // integer (32-bit wide => 32 column max)
  _dots = (unsigned int **)malloc(config->num_rows * sizeof(unsigned int *));
  _next_dots =
      (unsigned int **)malloc(config->num_rows * sizeof(unsigned int *));
  for (unsigned char i = 0; i < config->num_rows; ++i) {
    _dots[i] =
        (unsigned int *)calloc(config->num_modules, sizeof(unsigned int));
    _next_dots[i] =
        (unsigned int *)calloc(config->num_modules, sizeof(unsigned int));
  }
}

// copy current state _next_dots to _dots
void Flippie::cycle_dots() {
  memcpy(_dots, _next_dots, config->num_rows * sizeof(unsigned int *));
  for (unsigned char i = 0; i < config->num_rows; ++i) {
    memcpy(_dots[i], _next_dots[i], config->num_modules * sizeof(unsigned int));
  }
}

// paint content of _next_dots
// only paint differnces to _dots unless override is true (default = false)
void Flippie::paint(bool override_former_dot_state) {
  debug_printf("Start painting with override=%s ... ",
               override_former_dot_state ? "true" : "false");
  for (unsigned char i = 0; i < config->num_rows; ++i) {
    for (unsigned char j = 0; j < config->num_modules; ++j) {
      for (unsigned char k = 0; k < config->num_columns[j]; ++k) {
        if (override_former_dot_state ||
            (_dots[i][j] & _int_bit_array[k]) !=
                (_next_dots[i][j] & _int_bit_array[k])) {
          _set_dot(i, j, k,
                   (_next_dots[i][j] & _int_bit_array[k]) == _int_bit_array[k]
                       ? 1
                       : 0,
                   false);
          fire_shift_register(true);
        }
      }
    }
  }
  // _next_dots are the new _dots
  cycle_dots();
  if (DEBUG)
    debug_printf(" DONE.\n");
  else if (config->verbose)
    Serial.printf("Done painting _next_dots.\n");
}
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

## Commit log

2016-11-05 Added BOM
2016-11-07 Some clean-ups
    [flippie.brd, flippie.sch]
2016-11-07 Updated BOM
2016-11-10 Continue to write README documentation
    [flipdot.sch]
2016-12-28 Update board to rev10
    [brose_24v_logic.sch, flippie.brd, flippie.sch]
2017-01-13 Corrected R_set value for less current at VS
